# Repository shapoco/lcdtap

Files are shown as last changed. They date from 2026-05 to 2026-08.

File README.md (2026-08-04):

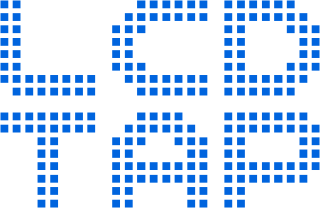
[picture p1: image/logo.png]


A library and its example design that receives LCD controller commands (via SPI or I2C)
and outputs the framebuffer as a DVI-D signal.

## Overview

See [introduction page](https://shapoco.github.io/lcdtap/).

## Implementations

### [LcdTap-Pico2 Universal](example/pico2_universal/)

Supports multiple LCD controllers (ST7789, ILI9341, SSD1306, SSD1331, ST7032)
and interfaces, selectable at runtime via an OSD menu.

### [LcdTap-Pico2W Remote](example/pico2w_remote/)

Raspberry Pi Pico 2 W version with no video output: the captured screen is
read over WiFi through an HTTP JSON API and a built-in web UI
(`http://lcdtap.local/`). WiFi setup via the
[Remote Setup page](https://shapoco.github.io/lcdtap/remote/) (WebSerial).

## License

MIT License — see [LICENSE](LICENSE).

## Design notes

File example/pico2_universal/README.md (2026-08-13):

# LcdTap-Pico2 Universal

A universal LCD-to-DVI converter example for Raspberry Pi Pico 2. With an OSD (On-Screen Display) menu for runtime configuration.

## Features

- Supports four input interfaces selectable via OSD: I2C, 4-Line SPI, 3-Line SPI, 8-bit Parallel
- Runtime configuration via OSD menu: interface, controller type, pixel format, LCD size, inversion, R/B swap, rotation, scale mode
- Settings (including selected interface) saved to flash on Apply and restored at next boot
- DVI output: 640×480@60Hz or 1280×720@30Hz selectable via GPIO21 at boot
- Composite video output (NTSC/PAL) on otherwise-unused GPIOs, selectable from the OSD: a 1-pin PWM DAC or a 7-bit R-2R ladder
- DisplayLink output: drives a USB graphics adapter (DisplayLink DL-1x0/1x5) at 1280×720 or 1920×1080@60Hz via a PIO USB Full-Speed host on GPIO10/11 (best-effort update rate)
- USB CDC serial interface for remote configuration and framebuffer readout from a PC or smartphone

> [!WARNING]
> Parallel Mode has not been tested yet. Please let me know if it works!

## Schematics

- Keep the input bus as short as possible and ensure all cables are the same length.
- See also: [Recommended Header Pinout](https://shapoco.github.io/lcdtap/#header_pinout)

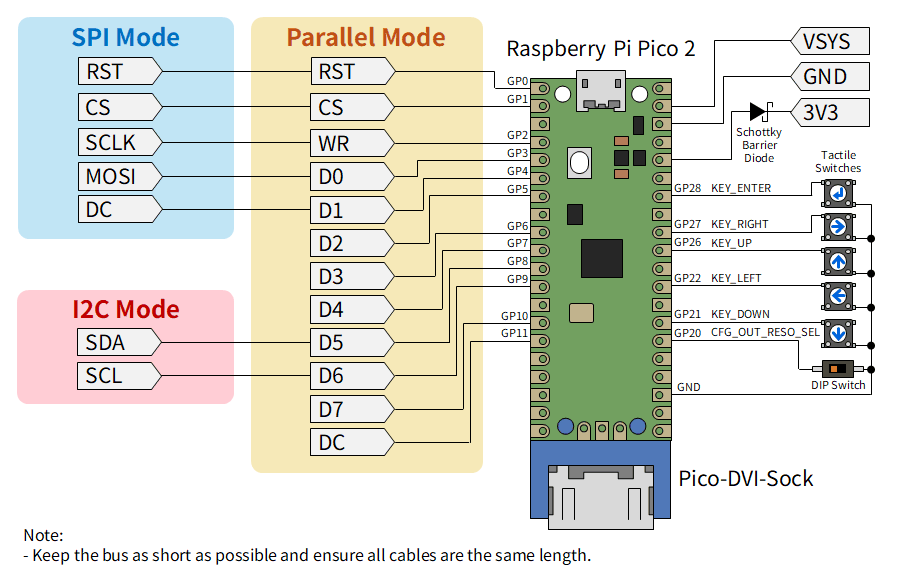
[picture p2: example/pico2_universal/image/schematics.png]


## GPIO Assignments

### Common (all modes)

| GPIO  | Direction | Name | Active-low | Internal Pull-up | Description |
|:--:|:--:|:--|:--:|:--:|:--|
| 0 | IN | RST | v | v | LCD Hardware reset (SPI mode) |
| 5–11  | OUT | CVBS_D[0..6] | | | Composite R-2R ladder (SPI modes only, when selected) |
| 10 | OUT | CVBS_PWM | | | Composite PWM output (SPI/I2C, when selected) |
| 10/11 | I/O | USB_DP / USB_DM | | | DisplayLink USB host D+/D- (SPI/I2C, when selected) |
| 12–19 | OUT | (DVI signals) | | | RP2350 HSTX |
| 20 | IN | CFG_OUT_RESO_SEL | v | v | High=640×480@60Hz,<br>Low=1280×720@30Hz |
| 21 | IN | KEY_DOWN | v | v | Low=pressed |
| 22 | IN | KEY_LEFT | v | v | Low=pressed |
| 26 | IN | KEY_UP | v | v | Low=pressed |
| 27 | IN | KEY_RIGHT | v | v | Low=pressed |
| 28 | IN | KEY_ENTER | v | v | Low=pressed |

### I2C Mode

| GPIO  | Direction | Name | Active-low | Internal Pull-up | Description |
|:--:|:--:|:--|:--:|:--:|:--|
| 8 | IN | SDA | | v | I2C data |
| 9 | IN | SCL | | v | I2C clock |

### 4-Line/3-Line SPI Mode

| GPIO  | Direction | Name | Active-low | Internal Pull-up | Description |
|:--:|:--:|:--|:--:|:--:|:--|
| 1 | IN | CS | v | v | LCD Chip select |
| 2 | IN | SCLK | | | SPI clock from master |
| 3 | IN | MOSI | | | SPI data from master |
| 4 | IN | DC | | | D/C# signal from master (4-line mode only) |

### Parallel Mode

| GPIO  | Direction | Name | Active-low | Internal Pull-up | Description |
|:--:|:--:|:--|:--:|:--:|:--|
| 1 | IN | CS | v | v | LCD Chip select|
| 2 | IN | WR | | | Write strobe |
| 3–10 | IN | D[0..7] | | | parallel data |
| 11 | IN | DC | | | D/C# signal |

For text displays, connect the R/W signal to CS and the E signal to WR.

For KS0108-compatible displays (such as SG12864), connect CS1 to RST,
CS2 to CS, and AND the inverted R/W signal with the E signal to connect to WR.
If R/W is fixed to Low, you can connect the E signal directly to the WR terminal.

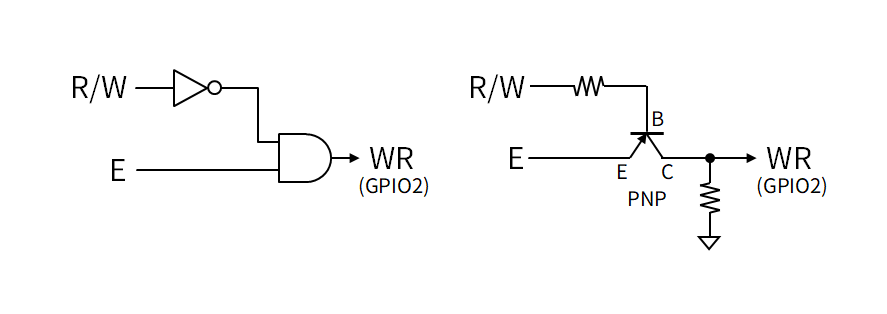
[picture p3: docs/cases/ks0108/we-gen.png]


## Composite Video Output (NTSC/PAL)

The HDMI connector occupies GPIO12–19, so composite video uses the GPIOs that
the input bus leaves free. Two independent OSD items control it (or
`outputInterface` / `compositeDac` over USB CDC):

- **`Output`** — `DVI-D`, `NTSC` or `PAL`
- **`Composite DAC`** — `PWM` or `R-2R`

There are therefore two quality tiers, and you only build the one you want:

| DAC | GPIO | Parts | Picture | Buses |
|:--|:--|:--|:--|:--|
| **PWM** | 10 | 1 resistor + 1 capacitor | ~12 luma steps, ~70% amplitude | SPI, I2C |
| **R-2R** | 5–11 | 14 resistors, no buffer | 7-bit luma, full amplitude | SPI only |

The R-2R ladder spans GPIO5–11, which covers the I2C pins (GPIO8/9), so it is
selectable only on SPI; the OSD greys it out otherwise. Composite output is
unavailable on the parallel bus entirely — GPIO3–10 are data lines there, which
covers the PWM pin too.

**The device resets** when `Output` changes (each mode needs a different system
clock), and when the bus or the DAC changes while a composite mode is running.

PAL colour is not implemented yet; PAL currently outputs monochrome on both
DACs.

> [!NOTE]
> Both DACs share GPIO10, so the two circuits are alternative populations, not
> simultaneous ones. Build whichever tier you want.

### PWM DAC — simple tier

One GPIO, one resistor, one capacitor. No buffer.

```
GPIO10 --- R ---+--- RCA centre
                |
                C
                |
               GND
```

The PWM period equals the sample period, so the duty resolution *is* the
sample period in system clocks: 22 steps on NTSC, 17 on PAL. White sits at
duty 17/22 rather than 100%, because chroma overshoots white by up to
+133 IRE and has to fit above it.

That, plus the 12 mA per-pin limit, is why the amplitude falls short of the
1 V standard — a single 3.3 V GPIO simply cannot reach it:

| R | White level | Sync amplitude | Peak current |
|:--|:--|:--|:--|
| 120 Ω | 0.78 V (78%) | 0.23 V (80%) | 13.5 mA |
| **150 Ω** | **0.70 V (70%)** | **0.21 V (72%)** | **12.0 mA** |
| 180 Ω | 0.63 V (63%) | 0.18 V (64%) | 10.8 mA |

Start at **R = 150 Ω** and drop to 120 Ω if a receiver refuses to lock.
Most TVs slice sync on the AC-coupled signal and tolerate this; capture
devices are less forgiving. C = 100–470 pF (corner ≈ 5–6 MHz).

The PWM carrier sits at 14.3 MHz with chroma at 3.58 MHz — only two octaves
apart — so a single-pole RC leaves visible carrier ripple. That is the
accepted cost of this tier.

### R-2R ladder — quality tier

The ladder drives the 75 Ω line **directly, with no buffer**. To deliver the
~1 V composite range into 75 Ω, its output impedance has to be low, so the
resistors are ~10× smaller than a textbook ladder: **R = 100 Ω series, 2R =
200 Ω rungs, 200 Ω termination.**

The firmware drives GPIO5 as the **LSB** and GPIO11 as the **MSB** (the PIO
maps sample bit 0 to the lowest GPIO). In an R-2R ladder the bit nearest the
output node has the greatest weight, so the **output is tapped at the GPIO11
(MSB) end** and the termination sits at the GPIO5 (LSB) end. Sync tip is 0 V at
the ladder, so it connects straight to the RCA centre — no coupling capacitor.

```
GPIO11 -- 200R --+---------------- RCA centre       (MSB, weight 64)
        (MSB)    |            |
               100R        (470pF)   optional reconstruction
                |            |        cap to GND (~6 MHz)
GPIO10 -- 200R --+          GND
                 :   (GPIO9, 8, 7, 6 identical)
               100R
                |
GPIO5  -- 200R --+                                  (LSB, weight 1)
        (LSB)    |
               200R    (2R termination)
                |
               GND
```

Wiring it the other way round — output at GPIO5, termination at GPIO11 —
reverses the bit weights and scrambles the picture, so double-check the
orientation.

2R = 200 Ω keeps the exact 2:1 R-2R ratio against the 100 Ω series resistor,
and in practice gives the most stable picture. The termination is another
200 Ω, so every rung and the termination share the same value.

Peak GPIO current is ~13 mA — just over the nominal 12 mA, which is fine here.
The drive strength stays at 12 mA (set in firmware).

> [!NOTE]
> These are a bench starting point. With a scope on a **50 % grey** field,
> confirm the mid-scale step is clean and monotonic.
>
> With nominal values the levels come out a few percent high (full scale
> ~1.4 V, white ~1.1 V, blanking ~0.3 V; sync tip 0 V). Trim this by scaling
> all three resistor families up together, or just leave it — the receiver
> works on relative levels. **Do not** retune it with `lvlWhite` / `lvlBlank`
> in `composite_timing.cpp`: those are shared with the PWM DAC. Use 1 %
> resistors, and keep 2R = 200 and the termination = 200 as a matched set.

## DisplayLink Output (USB)

Select `DisplayLink` as the `Output` (or `outputInterface = 3` over USB CDC) to
drive a USB graphics display adapter instead of the HDMI connector. The
adapter is driven by a PIO-based USB **Full-Speed** host
([Pico_USB_Disp](https://github.com/htlabnet/Pico_USB_Disp)) on GPIO10 (D+)
and GPIO11 (D−), so only the **DisplayLink DL-1x0 / DL-1x5** generation
works — newer chips (DL-3xxx and later) require High-Speed and encrypted
protocols. 1920×1080 needs a DL-165 or DL-195; smaller chips automatically
fall back to 1280×720.

- **Resolution** follows the CFG_OUT_RESO_SEL pin: open = 1280×720@60Hz,
  low = 1920×1080@60Hz (the DVI 480p/720p slots map to 720p/1080p).
- The adapter scans out a stable 60 Hz signal from its own framebuffer; the
  Pico streams **best-effort partial updates** over the ~1 MB/s bulk link.
  Only lines whose pixel values actually changed are re-sent, so mostly
  static screens update quickly; a full-screen change takes on the order of
  0.3–1 s (tearing can occur — there is no vsync over USB).
- Unavailable on the parallel bus (GPIO10/11 are D[7] and D/C# there), and
  mutually exclusive with the composite DACs, which share GPIO10.

Hardware: wire a USB-A receptacle with **5 V bus power (500 mA class)** to
the adapter, D+/D− to GPIO10/11. The 3.3 V GPIO levels match USB FS
signalling directly; series damping resistors up to ~47 Ω are tolerable at
Full-Speed (22–27 Ω preferred).

## Uploading Firmware

1. Download zip file from [releases](https://github.com/shapoco/lcdtap/releases).
2. Extract `lcdtap_pico2_universal.uf2` from the zip file.
3. Connect the Pico 2 to your computer while holding the BOOTSEL button to enter bootloader mode.
4. Copy the UF2 file to the mounted drive.

## OSD Menu

Press the Enter key to open the configuration menu.

| Key | Action |
|-----|---|
| Up / Down | Navigate menu items |
| Left / Right | Adjust selected value |
| Enter on Apply | Apply changes and save to flash |
| Enter on Cancel | Discard changes and close |
| Enter on Command Dump | Open the command dump viewer |

### Command Dump Viewer

Selecting **Command Dump** opens a hex viewer that shows the raw LCD command/data stream captured since power-on (or since the last trigger).

| Key | Action |
|-----|---|
| Enter | Clear buffer and start a new capture |
| Right | Stop capture (mark complete) |
| Left | Return to the configuration menu |
| Up / Down | Scroll |

Each row displays 16 entries. Colors indicate the type of each entry:

| Color | Meaning |
|---|---|
| Black on cyan | Command byte |
| White on black / dark-gray (alternating) | Data byte |
| Black on yellow (`HR`) | Hardware reset event |
| `..` in dark gray | Empty (not yet captured) |

## USB Serial Interface

LcdTap-Pico2 Universal accepts JSON commands over the USB CDC serial interface.
This allows remote configuration and framebuffer readout from a PC.

Available here: https://shapoco.github.io/lcdtap/monitor

## Building Firmware from Source

```bash
export PICO_SDK_PATH=/path/to/pico-sdk
./build.sh
```

The UF2 file is generated at `build/lcdtap_pico2_universal.uf2`.

### CMake Options

| Option | Default | Description |
|---|---|---|
| `LCDTAP_LCD_SIZE_W` | 240 | Initial LCD framebuffer width (px) |
| `LCDTAP_LCD_SIZE_H` | 320 | Initial LCD framebuffer height (px) |

Example:

```bash
cmake .. -DCMAKE_BUILD_TYPE=Release -DPICO_BOARD=pico2 \
         -DLCDTAP_LCD_SIZE_W=320 -DLCDTAP_LCD_SIZE_H=240
```

## External Deserializer for High-Speed SPI

The SPI interface of LcdTap-Pico2 Universal can support clock frequencies up to approximately 50MHz. For frequencies exceeding this, you can add an external deserializer outside the Pico2 to support higher speeds. In this case, select Parallel as the Interface in the OSD menu.

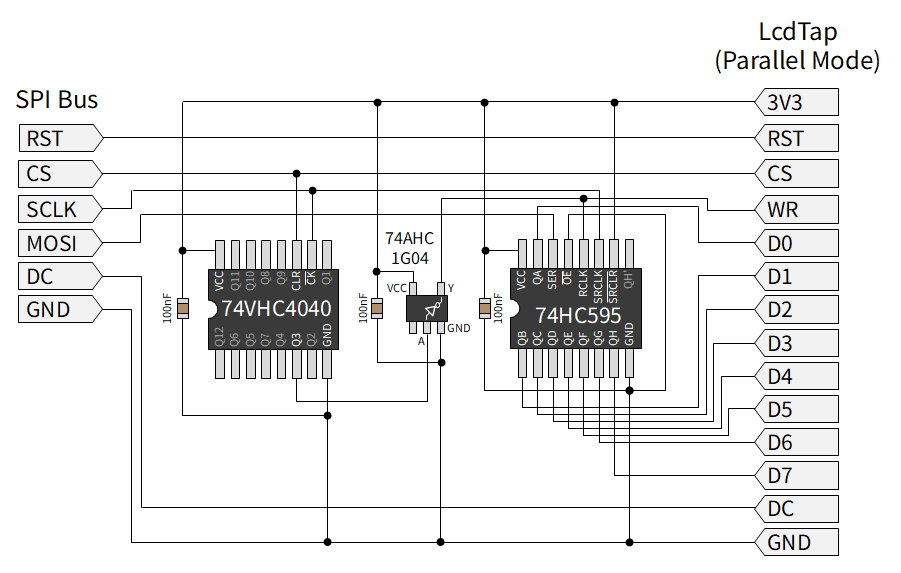
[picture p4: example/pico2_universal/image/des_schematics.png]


## Troubleshooting

### Failed to boot normally

Try powering on or resetting while pressing the Left key. This will boot while ignoring the settings saved in flash.

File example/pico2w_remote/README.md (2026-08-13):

# LcdTap pico2w_remote

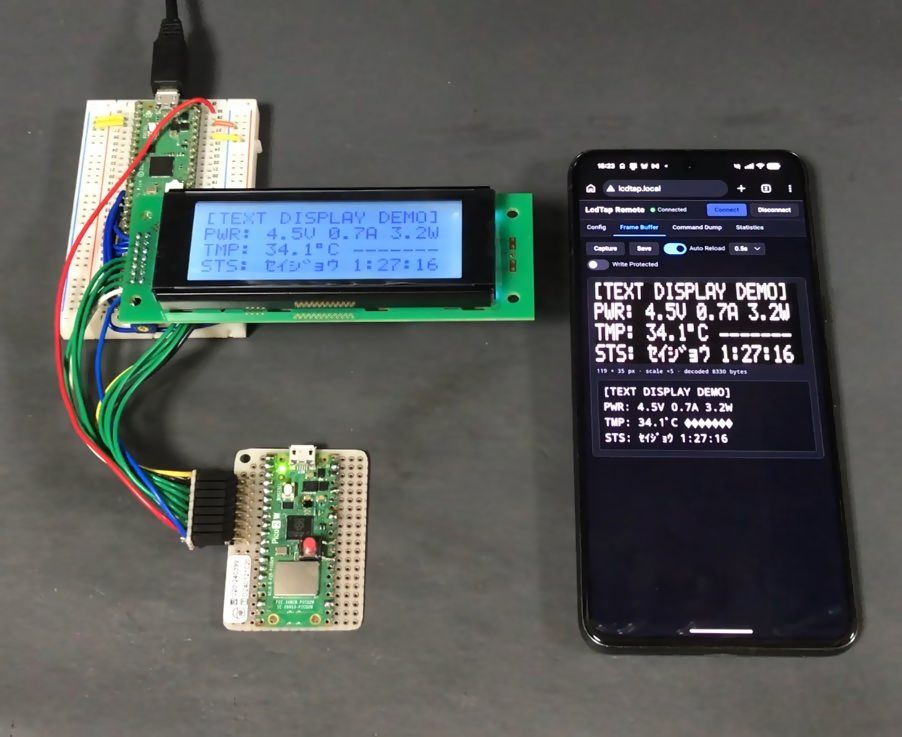
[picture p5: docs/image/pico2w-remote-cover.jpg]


LcdTap implementation for Raspberry Pi Pico 2 W. Using the same input interface as
pico2_universal (I2C / 4-wire SPI / 3-wire SPI / 8-bit parallel with identical pin layout),
it captures LCD controller traffic and reads the screen **without video output** via WiFi
through HTTP JSON API and built-in Web UI on the device.

## Features

- HTTP Server (port 80)
  - `GET /` — Web page with the same UI as LcdTap Monitor (firmware built-in)
  - `POST /api` — Same JSON command set as pico2_universal's UART I/F
- USB CDC Serial — Same JSON command set + WiFi setup
  (`getnetconfig` / `setnetconfig` / `netstatus`)
- mDNS — `http://<hostname>.local/` (default `lcdtap.local`)
- Settings are stored in Flash

## Setup

1. Download the latest zip file from [releases](https://github.com/shapoco/lcdtap/releases), and extract `lcdtap_pico2w_remote.uf2`.
2. Connect Raspberry Pi Pico 2 W to your PC while holding the BOOTSEL button, and copy the uf2 file to the mounted drive.
3. Open [LcdTap Remote Setup](https://shapoco.github.io/lcdtap/remote/) in your browser,
   connect via WebSerial, and write SSID / passphrase, etc.
4. Pico2W reboots and attempts WiFi connection. When connection succeeds,
   LED stays on, and you can open Web UI at `http://lcdtap.local/` (or IP address).

## LED

| State | Pattern |
|---|---|
| WiFi Not Configured | 0.25 s on / 0.75 s off |
| Connecting | 0.25 s on / 0.25 s off |
| Connection Failed (Retry Waiting) | 0.5 s on / 0.5 s off |
| Connected | Always on + 50 ms off pulse on access |

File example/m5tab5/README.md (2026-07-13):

# LcdTap-Tab5

An implementation example that lets the Tab5 act as an SPI/I2C-connected LCD
display. It receives LCD controller commands on the rear port (M-Bus /
Grove) and renders them via M5GFX onto the built-in 1280x720 MIPI-DSI panel.

## Features

### I2C slave

Use the Grove connector on the side of Tab5 as an I2C slave and draw on the
Tab5 screen using SSD1306-compatible commands. The I2C slave address is 0x3C.

### SPI slave

Use the M-Bus connector on the back of Tab5 as an SPI slave and draw on the
Tab5 screen with 4-wire SPI (MOSI/D/C/CS).
All signals including RST must be connected.

The input interface has I2C selected by default.
To switch to SPI, select 4-Line SPI in the Interface menu of the OSD.

### OSD and keypad

When you tap the screen, a semi-transparent keypad appears on the screen.
Tap the return key icon to open the OSD menu where you can change various settings.
Settings are saved on the Tab5 device.

### Support for controllers other than SSD1306

Other controllers besides SSD1306 can be selected in the OSD, but
they may not work correctly due to performance and hardware constraints.

## Wiring

| Signal | GPIO | Location | Notes |
|---|---|---|---|
| SPI SCK | G17 | M-Bus ||
| SPI MOSI | G16 | M-Bus ||
| SPI D/C | G18 | M-Bus | |
| SPI CS | G45 | M-Bus | active-low, pulled up |
| RST | G19 | M-Bus | active-low, pulled up, shared by SPI/I2C |
| (reserved) | G52 | M-Bus | Dummy clock for priming. **Leave unconnected** |
| (reserved) | G51 | M-Bus | CS substitute for priming (driven High). **Leave unconnected** |
| I2C SDA | G53 | Grove | Slave address 0x3C |
| I2C SCL | G54 | Grove | External pull-up (2.2k-10kΩ) recommended |

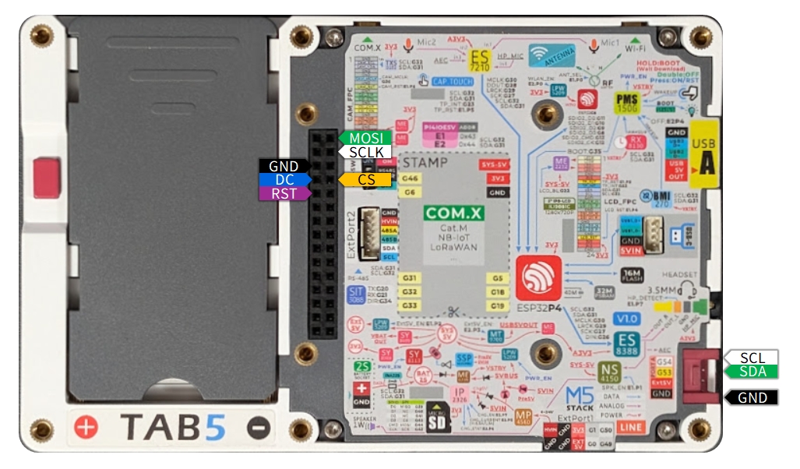
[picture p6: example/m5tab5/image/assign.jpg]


Notes on I2C wiring:

- Signal level is **3.3V only** (the ESP32-P4 is not 5V tolerant).
- If the original display is left connected in parallel on the bus, the
  address 0x3C collides, but reception (wired-AND) still works for both.
- Since clock stretching is not performed, this also works alongside
  bit-bang masters that don't check SCL (in exchange, reads return
  best-effort dummy values).

## Pre-built firmware

Pre-built firmware is available on the [M5Burner](https://docs.m5stack.com/en/uiflow/m5burner/intro). Search for "LcdTap".

## Build

Uses native ESP-IDF (idf.py). **ESP-IDF v5.5.x is required**
(the ESP-IDF build of M5GFX/M5Unified has only been verified up through
the v5.5.x series, and `i2c_slave.cpp` also requires
`ESP_IDF_VERSION >= 5.5`; v6.0 is not supported).

```sh
source <path-to-ESP-IDF>/export.sh
idf.py set-target esp32p4
idf.py build              # build
idf.py -p <PORT> flash    # flash
idf.py -p <PORT> monitor  # serial log (115200 bps)
```

Display, touch, IMU, and power bring-up use M5Unified/M5GFX as ESP-IDF
components (pulled in via `main/idf_component.yml`; `m5stack/m5gfx` is
pinned to an exact version because `async_blit.cpp` obtains the DSI
panel's raw framebuffer via an internal header).

The core library `lib/` is pulled in as an IDF component via
`EXTRA_COMPONENT_DIRS` in `CMakeLists.txt` (the `ESP_PLATFORM` branch in
`lib/CMakeLists.txt`). Its component name under IDF is derived from the
directory name, `lib` (see `REQUIRES` in `main/CMakeLists.txt`).

## Limitations / Notes

- Only **I2C** and **SPI (4-wire)** buses are supported. SPI 3-wire and
  8-bit parallel are not supported (selecting them in the OSD is
  ignored).
- Screen refresh is best-effort (LcdTap's framebuffer is transferred to
  the DSI panel in strips).
- The maximum SPI clock depends on the upper limit of PARLIO RX's
  external clock. Around 50 MHz is the target, but this needs to be confirmed
  by measurement on real hardware, including the effect of GPIO matrix
  delay.

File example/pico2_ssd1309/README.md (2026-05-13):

# Sample program for Raspberry Pi Pico2 — SSD1309

## Build instructions

```bash
cd example/pico2_ssd1309
mkdir build && cd build
cmake .. -DPICO_SDK_PATH=/path/to/pico-sdk
make -j4
```

## Input modes

This example supports two input modes, selectable via GPIO 20 at startup.

### I2C mode (default)

Connect the SSD1309 SDA and SCL lines directly to GPIO 0 and GPIO 1 with
4.7 kΩ pull-ups to 3.3 V. The Pico 2 acts as an I2C slave at address
`0x3C` (SA0 tied low). The SSD1309 I2C control byte (first byte after the
address phase) is decoded to determine whether subsequent bytes are commands
or GDDRAM data.

### SPI mode

SPI commands are received via a parallel conversion circuit — see
[example/pico2\_st7789/README.md](../pico2_st7789/README.md) for the full
description of the 74HC595 + 74HC4040 + 74AHC1G04 wiring and the BCLK/DCX signal path.
The pin assignment is identical to the ST7789 example.

## Pin assignment

| GPIO  | Direction | Function |
|---|---|---|
| 0 | IN | I2C SDA (I2C mode only) |
| 1 | IN | I2C SCL (I2C mode only) |
| 2 | IN | BCLK — byte clock = SCLK÷8 (SPI mode, 74AHC1G04 output, HIGH when byte complete) |
| 3 | IN | DCX — D/C# signal (SPI mode, direct from SPI master) |
| 4–11  | IN | D[0..7] — parallel data (SPI mode, 74HC595 Q1–Q8 outputs) |
| 12–19 | OUT | DVI TMDS output (pico\_sock\_cfg, driven by PicoDVI) |
| 20 | IN | CFG: input mode select |
| 21 | IN | CFG: DVI output resolution select |
| 22 | IN | RESX — hardware reset, active-low (SPI mode, pull-up on board) |
| 25 | OUT | Onboard LED |
| 26 | IN | CFG: output rotation bit 0 |
| 27 | IN | CFG: output rotation bit 1 |

## Configuration GPIOs

All configuration pins are read once at startup with internal pull-downs
(default = LOW). Pull HIGH to select the alternate option.

The output rotation is re-checked every DVI frame; changes take effect on the
next frame without restarting.

| GPIO  | Name | LOW (default) | HIGH (alternate) |
|---|---|---|---|
| 20 | INPUT\_MODE | I2C mode (default) | SPI mode |
| 21 | DVI\_RES | 640×480 @ 60 Hz | 1280×720 @ 30 Hz (reduced) |
| 26+27 | ROT | 00 = no rotation | 01/10/11 = see table below |

`ROT` is a 2-bit field: GPIO 27 is bit 1 (MSB) and GPIO 26 is bit 0 (LSB).

| ROT value | Effect |
|---|---|
| `00` | No rotation (default) |
| `01` | 90° clockwise — aspect ratio swapped for FIT |
| `10` | 180° / flip |
| `11` | 270° clockwise — aspect ratio swapped for FIT |

The scale mode is fixed to **FIT** (aspect-ratio-preserving letterbox /
pillarbox). The SSD1309 display is 128×64 pixels.

## DVI output (PicoDVI / libdvi)

DVI output is handled by [PicoDVI](https://github.com/Wren6991/PicoDVI)
(`libdvi`).

- **Core 1** runs `dvi_scanbuf_main_16bpp()` in an infinite loop, consuming
  RGB565 scanline buffers from the `q_colour_valid` queue and serialising TMDS
  data to the DVI connector via PIO0 and DMA.
- **Core 0** (main loop) calls `inst.fillScanline()` for each line and
  pushes the filled buffer to `q_colour_valid`.

The system clock is raised to match the TMDS bit-clock requirement (252 MHz for
640×480, 319.2 MHz for 1280×720 reduced), and the voltage regulator is set to
1.20 V to support these higher frequencies.

PicoDVI uses PIO0 and claims its DMA channels inside `dvi_init()`. In SPI mode,
the parallel slave PIO program runs on PIO1 (SM0), and its DMA channel is
claimed after `dvi_init()` to avoid conflicts.

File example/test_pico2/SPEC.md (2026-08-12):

# LcdTap Test Rig (test_pico2)

A Raspberry Pi Pico 2 W based semi-automated hardware test rig for the
LcdTap `pico2_universal` target. The rig plays the role of the LCD host:
it configures the target over its USB CDC JSON protocol, drives LCD
controller command streams into the target's SPI / I2C / 8-bit parallel
input as a bus master, reads the resulting framebuffer (or text buffer)
back over CDC, and verifies it against the transmitted pattern.

DVI-D / composite / DisplayLink outputs are checked visually and are out
of scope for automatic verification.

```
 PC ── USB ──┐                     ┌──────────────┐
             │  ┌──────────────┐   │ pico2_universal
   (console, │  │  Test rig    │───│  (target)
    Phase 2: ├──│  Pico 2 W    │   │
    UF2 pass │  │              │───│ LCD bus in
    through) │  └──────────────┘   └──────────────┘
             │     │        │
             │   OLED    keys x5
```

## Roles and phases

- **Phase 1 (this firmware)**: test execution. USB CDC host to the
  target (JSON protocol), bus master TX, streaming verification, OLED UI.
  Target BOOTSEL (MSC) presence is *detected* and shown as
  "Download Mode".
- **Phase 2 (implemented, on by default)**: USB MSC passthrough — while
  the target is in BOOTSEL, the rig exposes the RPI-RP2 drive to the PC
  ("TestRig Storage") and forwards UF2 writes, ported from the proven
  `mimicusb` project (`src/msc_bridge.cpp`): core 0 device callbacks
  defer with `TUD_MSC_RET_BUSY` while a single-slot cross-core handshake
  runs the block transfer on the core 1 host stack; target attach/detach
  is reported as SCSI media insert/remove (Unit Attention 0x28 / Not
  Ready 0x3A), so the drive letter stays put and only the medium comes
  and goes. Disable with `-DTESTRIG_MSC_PASSTHROUGH=0`. Note: MSC IO is
  only serviced while the UI is idle or between executor steps — do not
  flash the target while a test run is active.

## Hardware

### MCU / board

Raspberry Pi Pico 2 W (RP2350). The onboard LED (CYW43 WL_GPIO0) is a
heartbeat.

### Pin assignment

The bus port is wired straight to the target: **rig GPIO N → target
GPIO N−10**.

| Rig GPIO | Function | Target GPIO |
|---:|---|---:|
| 0 | UI OLED SDA (I2C0) | — |
| 1 | UI OLED SCL (I2C0) | — |
| 2 | Inc key (low active, pull-up, auto-repeat) | — |
| 3 | Dec key (low active, pull-up, auto-repeat) | — |
| 4 | Start key (low active, pull-up) | — |
| 5 | Select key (low active, pull-up) | — |
| 6 | Back key (low active, pull-up) | — |
| 8 | USB host D+ (Pico-PIO-USB) | target USB D+ |
| 9 | USB host D− | target USB D− |
| 10 | RST (active low) / 2CS: CS1 (high active) | 0 |
| 11 | CS (active low) / 2CS: CS2 (high active) | 1 |
| 12 | WR# / SCLK / 2CS: /EW strobe | 2 |
| 13 | D0 / SPI MOSI | 3 |
| 14 | D1 / SPI DC | 4 |
| 15–17 | D2–D4 | 5–7 |
| 18 | D5 / I2C SDA (i2c1) | 8 |
| 19 | D6 / I2C SCL (i2c1) | 9 |
| 20 | D7 | 10 |
| 21 | Parallel DC | 11 |

Only the pins of the active bus are driven; everything else on GPIO11–21
is kept high-impedance.

In PARALLEL_2CS (KS0108/KS0108) mode the same wires change roles: the
rig drives the raw high-active CS1/CS2 selects and the /EW strobe
directly (the target expects /EW = NAND(E, /R/W); the 8080 WR# waveform
of `par8_master.pio` is exactly that pulse), so no external gate logic
is needed. There is no reset input in this mode.

### External components (required)

- **GPIO8/9: ~15 kΩ pull-downs to GND.** RP2350 erratum E9 makes the
  internal pull-downs unreliable as USB host bus-reset terminations.
- SSD1306 128x64 I2C OLED on GPIO0/1 (address 0x3C), plus I2C pull-ups
  if the module has none.
- I2C pull-ups on the target bus lines (rig GPIO18/19) are recommended
  for the 1 MHz / 2 MHz settings; both sides also enable internal
  pull-ups.
- The rig must supply VBUS to the target's USB port.

## Clocking and on-chip resources

- `clk_sys` = **240 MHz** (multiple of 12 MHz for PIO-USB) with
  `VREG_VOLTAGE_1_15`.
- The SPI spec point of 62.5 MHz is intentionally replaced by
  **60 MHz** (240 MHz / 2 cycles-per-bit / divider 2): 62.5 MHz would
  require a 125/250 MHz clock, which PIO-USB cannot run from.
- PIO allocation: pio0 = PIO-USB TX, pio1 = PIO-USB RX, pio2 SM0 = bus
  master (SPI or parallel program, loaded on demand), CYW43 LED SPI
  claims a remaining SM (the init order in `main.cpp` steers it to
  pio2).
- Core 0: device USB (PC console), UI, executor. Core 1: TinyUSB host
  stack over PIO-USB (mount callbacks, CDC FIFO pumps). The cores
  exchange CDC bytes through lock-free SPSC rings.
- TX pattern buffer: one static 307.2 KB buffer (`TX_BUFFER_SIZE`,
  320×480 RGB565). Larger wire frames (320×480 RGB666 = 460.8 KB) are
  generated and sent in row chunks inside a single RAMWR.

## Bus master details

| Bus | Implementation | Rates |
|---|---|---|
| SPI mode 0 | PIO (pio2), 2 cycles/bit, MSB first; DC on GPIO14 switched between command/data phases after a TXSTALL drain | 10 / 20 / 40 / 60 MHz |
| 8-bit parallel | PIO, 3 cycles/byte: data setup with WR# low, target latches on the rising edge, 2-cycle hold (the target samples D+DC ~26 ns after the edge) | graphic: 1 / 2.5 / 5 / 10 MHz; character LCDs: 2 / 5 / 10 / 20 kHz (real HD44780-class modules such as the SC2004 need ~100 µs per byte) |
| I2C | hardware i2c1; control-byte framing per the target's parser (first byte per transaction: bit6 = D/C, Co=0 streams the rest) | 100 k / 400 k / 1 M / 2 MHz |

- For ST7032 targets the parallel strobe is inverted with
  `gpio_set_outover()`: the inverted 8080 WR# waveform is exactly the
  6800 E timing the target expects (`parWrInvert` on the target side).
- 2 MHz I2C is beyond the FM+ spec; it relies on the DW I2C timing
  registers accepting the divider. Validate on hardware; the vector can
  be treated as expected-fail if the silicon disagrees.
- CS is asserted for the whole test sequence and released at the end
  (SPI modes: the CS rising edge resets the target's capture state
  machine; parallel mode: the target discards strobes while CS is high,
  issue 0014).

## Test vectors

33 built-in vectors plus the **ALL** entry (runs every vector, continues
on failure). Defaults use the "Fast" clock (third choice of each
family/bus list: I2C 1 MHz, SPI 40 MHz, parallel 5 MHz — 10 kHz for
character LCDs, 500 kHz for the dual-CS parallel bus). See
`src/vectors.cpp` for the
full table: SSD1306 (I2C rot 0–3, SPI), SSD1331 (RGB332 rot 0–3,
RGB565, RGB666-RA), ST7789 (RGB444 rot 0–3, RGB565, RGB666-LA),
ILI9341, ILI9488 (RGB111 rot 0–3, RGB565, RGB666-LA, trim CUSTOM/AUTO,
parallel), ST7032 text presets (8x2/16x2/16x4/20x4 I2C, 20x4
parallel), and KS0108/KS0108 on the dual-CS parallel bus
(`KS0108_P8C2` per-chip page streams; `KS0108_CsMix` alternates the
cs mask per data byte with no commands in between, covering the bare
cs-change batch split in the target's `spiSlaveProcess2Cs`). KS0108
behaviours already proven by the host test
`example/pico2_common/test_host/ks0108_test.cpp` (start-line scroll,
column wrap, flip, per-chip display off, cs=3 data duplication) are not
re-tested on the rig.

Customization (per selected vector, volatile): bus interface,
resolution, pixel format, rotation, trim (Off / Custom / Auto with
x=11, y=15, w=width/2, h=height/2). Choice lists are constrained per
controller family. The bus clock is not per-vector: the global speed
class from the title screen picks index 0-3 of the same per-family/bus
frequency lists.

Formats that the controller command set cannot express are forced via
the target's `intfFmtOvr` setting: SSD1331 RGB666-RA (SETREMAP encodes
only RGB332/RGB565) and ILI9341-family RGB111 (COLMOD 0x01 unmapped).
Everything else is selected through real COLMOD / SETREMAP commands.

## Test procedure (per vector)

1. `getparams` for the vector's base preset; capture `swapRB`,
   `i2cAddr`, `textCols/Rows`.
2. Echo all preset values back via `setparams` with the vector's
   overrides (`busInterface`, `buffWidth/Height`, `trimMode/X/Y/W/H`,
   `outputRot`, `intfFmtOvr`, `flipMode=0`, `forcePwrOn=0`,
   `outputInterface=0`) plus **`"save": false`** so flash is not worn by
   automated runs. Keeping `outputInterface` at DVI-D avoids target
   reboots.
3. Wait 300 ms, `statsreset`.
4. Select the bus, pulse RST (10 ms low, 120 ms settle), send the
   controller init sequence (SWRESET/SLPOUT/COLMOD/MADCTL/DISPON etc.).
   PARALLEL_2CS vectors skip the RST pulse — the RST line is the CS1
   select in that mode; the target's `inputReset` on the `setparams`
   bus switch provides the state init instead.
5. Send 10 solid-color dummy frames (one row built once, resent per
   line), then immediately one PRNG compare frame. KS0108: dummy pages
   are written to both chips at once (cs=3); after the compare frame a
   few data bytes and a garbage command are sent with **no** chip
   selected — the discard is verified by the unchanged compare result
   and the zero `Unknown Commands` delta.
6. `getframebuffer {"writeProtected": true}` — the Base64/RLE stream is
   decoded and compared on the fly (below). Character LCD vectors send
   dummy text then per-row pattern text and compare via
   `gettextbuffer` (exact character codes).
7. `getstats`: the deltas of `RX Drop`, `RX HW Overflow` and
   `Unknown Commands` must be zero.

Pass = pixel/text compare AND clean stats. The result screen reports
the failed stage, mismatch count and first bad coordinate.

### Trim vectors

Auto trim on the target expands from the *addressed window*
(CASET/RASET), not from pixel content. AUTO vectors therefore address
only the trim rectangle (window, dummy and compare frames all confined
to it) and expect the readback region to equal it exactly. CUSTOM
vectors send the full frame; the target reports only the trim region.

## Verification engine

- **Pattern**: a counter-based hash PRNG (`hash32(seed ^ physIndex)`)
  gives O(1) random access to any pixel's canonical 8-bit RGB channels.
  Wire encoders emit the top N bits per channel for the vector's
  format; the expected RGB565 value derives from the same channels, so
  no expected-frame buffer exists anywhere.
- **Streaming compare**: the `getframebuffer` payload is fed character
  by character through Base64 → RGB565-RLE → pixel decode. The target
  emits the trim region in post-rotation order (`fbIndexTrimmed`); the
  verifier applies the same mapping back to physical coordinates,
  recomputes the expected hash and compares under a per-format
  significant-bit mask (e.g. RGB444 compares the top 4 bits of each
  channel), which removes any dependency on the target's low-bit
  expansion policy. `swapRB` swaps the compared fields and mask widths.
- Display inversion needs no special handling: the target XORs pixels
  on write and `getframebuffer` XORs them again with the same flag.
- Peak readback is ~410 KB of Base64 at Full-Speed USB (~1 s); nothing
  is buffered.

## UI

128x64 OLED (LovyanGFX, 6x8 font) and five tact switches (all
low-active with internal pull-ups, 1 ms sampling, level accepted after
3 identical samples). The Dec/Inc keys auto-repeat while held: first
repeat after 500 ms, then every 100 ms.

- **Title screen** (boot): run-wide options. `Intf` selects the target
  link (CDC over the PIO-USB port, or WiFi against pico2w_remote);
  `Freq` selects the global bus speed class Slow/Medium/Fast/Extra
  (index 0-3 into each family/bus frequency list; default Fast).
  Inc/Dec change the focused value, Select moves the focus, Start
  enters vector select (persisting changed options to flash and, for
  WiFi, starting the rig-side join), Back is ignored. A status line
  shows the rig's WiFi state / IP while WiFi is selected.
- **Vector select**: Inc/Dec scroll ALL / #1..#31; the title blinks.
  Start runs, Select customizes (not on ALL), Back returns to the
  title screen. The `Freq` line shows the clock the speed class
  resolves to for the vector's bus (informational).
- **Item select**: Inc/Dec pick Intf/Freq/Reso/Fmt/Rot/Trim (text
  vectors: Intf/Freq only); the item name blinks. Select edits, Back
  returns.
- **Value select**: Inc/Dec change the candidate; the value blinks.
  Select applies, Back cancels.
- **Running**: vector name + percent; Back cancels (between steps).
- **Result**: big OK/NG; on NG the failed list scrolls with Inc/Dec
  and the detail line shows stage / mismatch count / first bad pixel. Select
  jumps to customization of the selected failure, Back to vector
  select.
- **Download Mode**: while the target enumerates as MSC, the OLED
  blinks "Download Mode" and inputs are ignored; the previous screen is
  restored on exit.

The PC-facing CDC console logs pass/fail lines via `printf`
(`pico_stdio_usb` cannot coexist with `tinyusb_host`, so a minimal
custom stdio driver feeds the device CDC).

## WiFi mode (pico2w_remote target)

With `Intf: WiFi`, the run talks to a pico2w_remote target over HTTP
(`POST /api`, same JSON protocol) instead of CDC:

- The rig joins the WLAN with credentials stored in its flash (settings
  page below); DHCP only. `cyw43_arch_lwip_poll` + a minimal raw-TCP
  HTTP client (`src/link_http.cpp`, response parsing in
  `src/http_client.cpp`, host-tested by `test_host/http_test.cpp`).
- **The target's IP is discovered automatically**: at the start of every
  run the rig sends `netstatus` over the USB CDC link (the rig and
  target stay USB-connected in WiFi mode too) and uses the reported
  address. No target address is configured anywhere. If the target is
  not `CONNECTED`, every selected vector fails fast with stage
  `target-wifi`; if the rig's own WiFi is down, stage is `link`.
- One TCP connection per command: the target answers chunked with
  `Connection: close`, and the transport synthesizes the terminating
  newline on completion, so `JsonClient` runs unmodified. A `503`
  (target busy) is retried up to 3 times with a 200 ms backoff.
- The bus wiring, RST pulse and verification pipeline are identical to
  CDC mode. Note pico2w_remote's RGB111-at-40MHz limitation: run the
  Medium speed class for a clean ALL pass.

### Rig settings page (docs/test-pico2/)

A Web Serial page (same stack as docs/remote/) configures the rig's
SSID / passphrase / country over its PC-facing CDC and shows the join
state. It speaks `hello` (expects `"welcome testrig"` — distinguishes
the rig from a target), `getrigconfig`, `setrigconfig` and `netstatus`;
non-JSON console log lines are filtered (`jsonOnly` option of
serial_conn.js). Settings persist in the rig's last flash sector
(pico2_common flash_store; core 1 is parked in SRAM around the write)
and apply without a reboot.

## JSON protocol usage

See `example/pico2_common/UART_PROTOCOL.md`. The rig added the
`"save": false` option to `setparams` (apply without persisting) —
without it, every `setparams` costs a flash sector erase and a Core 1
pause on the target. The transport is abstracted (`Transport` in
`include/testrig/link.hpp`: `sendLine`/`recvChar`); a future
pico2w_remote HTTP transport (`POST /api`, same JSON) can replace the
CDC implementation without touching the executor.

## Build

```sh
git submodule update --init submodule/Pico-PIO-USB \
    submodule/ArduinoJson submodule/LovyanGFX
cd example/test_pico2
PICO_SDK_PATH=... ./build.sh      # PICO_BOARD=pico2_w
```

Host-side unit tests (no hardware; the closed loop runs the real lcdtap
library and the target's own RLE/Base64 encoders):

```sh
cd example/test_pico2/test_host
# build commands are in the header comments of:
#   testgen_test.cpp  — wire encoders vs reference decoders
#   verify_test.cpp   — closed loop: testgen -> LcdTap -> serialize -> verify
```

The closed-loop test found and pinned lib issue 0013 (RGB666-LA red LSB
leaking into green bit 10) before any hardware existed.

## Known limitations / future work

- Target parallel input is marked untested in pico2_universal — expect
  to shake out target-side issues; start at 1 MHz.
- Rotation vectors validate the config path, input decode and the
  rotated readback mapping; the DVI-side rendering itself remains a
  visual check.

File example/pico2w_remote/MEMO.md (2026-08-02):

# 実装メモ

- コア分担は pico2_universal と逆: **Core 1** が入力ドレイン
  (バス IRQ も Core 1 の NVIC に登録)、**Core 0** が cyw43/lwIP ポーリング
  + HTTP + USB CDC + LED。62.5 MHz SPI 入力が lwIP の処理バーストに
  影響されないための構成。
- Flash 書き込みとバス切替は Core 0 → Core 1 のメールボックスで依頼する
  (書き込み中 Core 1 は SRAM 上で待機)。
- clk_sys は実績のある 312 MHz (`sysClockInit312`)。CYW43 の PIO SPI は
  `CYW43_PIO_CLOCK_DIV_INT=4` で 39 MHz に抑えている。
- Web UI は `docs/monitor/` の共有ファイル (device.html / monitor.css /
  monitor.js / http_conn.js) をビルド時に gzip 圧縮して取り込む
  (`tools/embed_assets.py`)。GitHub Pages 版 Monitor と単一ソース。
- HTTP API は同時 1 リクエスト (2 本目は 503)。認証・暗号化は無いので
  信頼できる LAN 内での使用を前提とする。パスフレーズは Flash に平文で
  保存され、`getnetconfig` はパスフレーズを返さない。
- 既知の制限: CDC と HTTP の両方から `writeProtected:true` の
  getframebuffer を同時に実行すると、先に完了した側が書き込み保護を
  解除する (もう一方のキャプチャにティアリングが出る可能性)。

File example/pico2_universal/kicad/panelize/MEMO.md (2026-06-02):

# JLCPCB で位置の修正が必要だったパーツ

注文時のプレビュー上で修正して注文した

- RP2350: 向き
- HDMIコネクタ: 向きと位置
- USBコネクタ: 位置
- 1.1V レギュウｰレータのコイル: 向き
- 3.3V レギュレータ: 向き
- スライドスイッチ: 位置

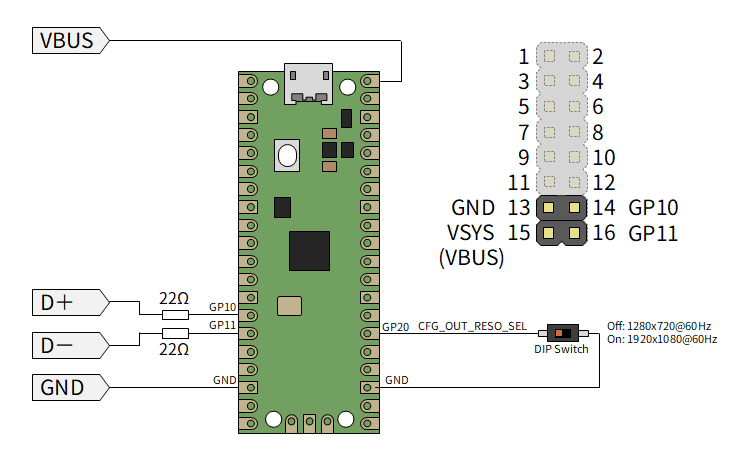
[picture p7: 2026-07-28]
docs/image/displaylink-out-schematics.png

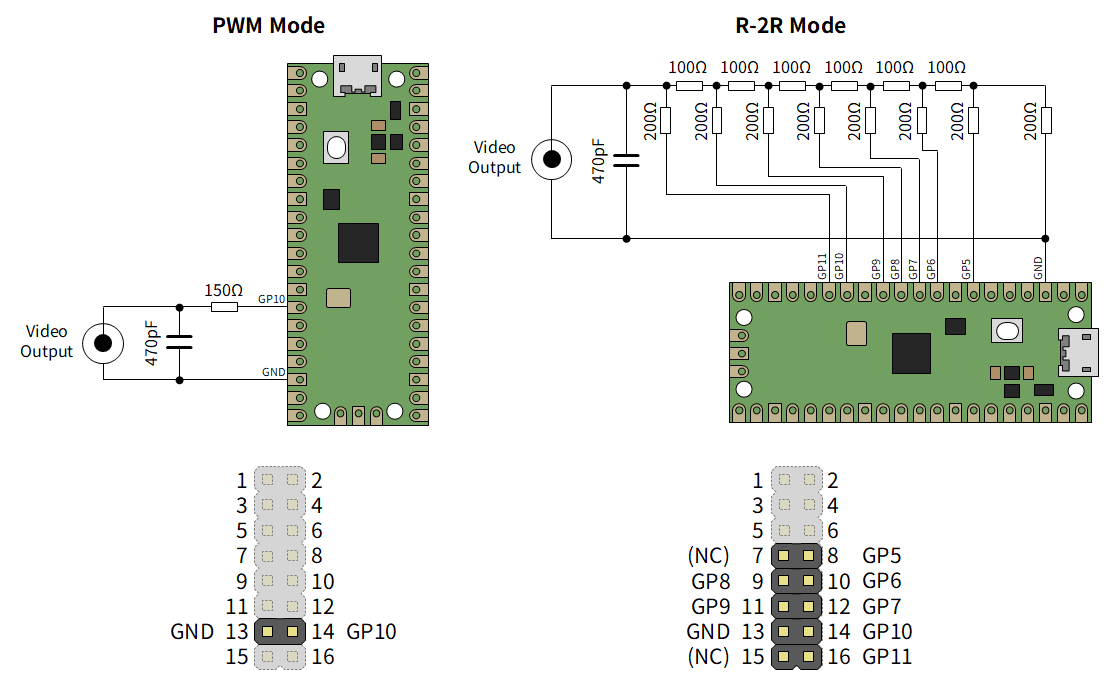
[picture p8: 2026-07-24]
docs/image/composite-out-schematics.png

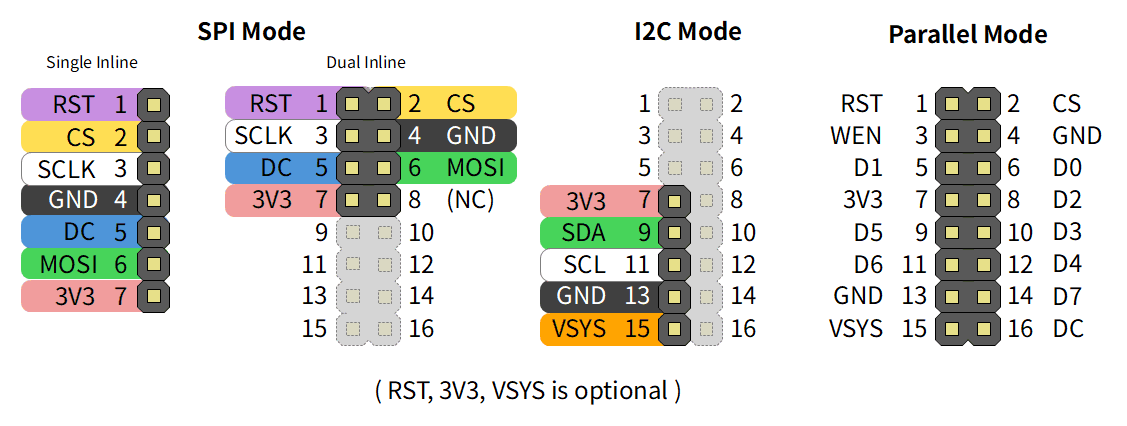
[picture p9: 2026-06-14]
docs/image/header-pinout.png

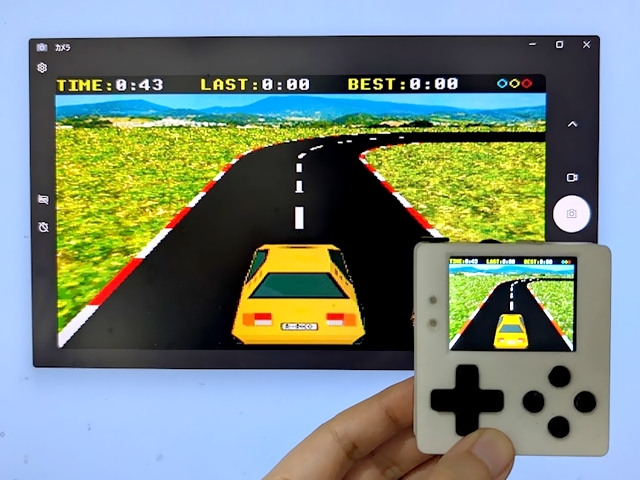
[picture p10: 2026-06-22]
docs/cases/picopad/thumb.jpg

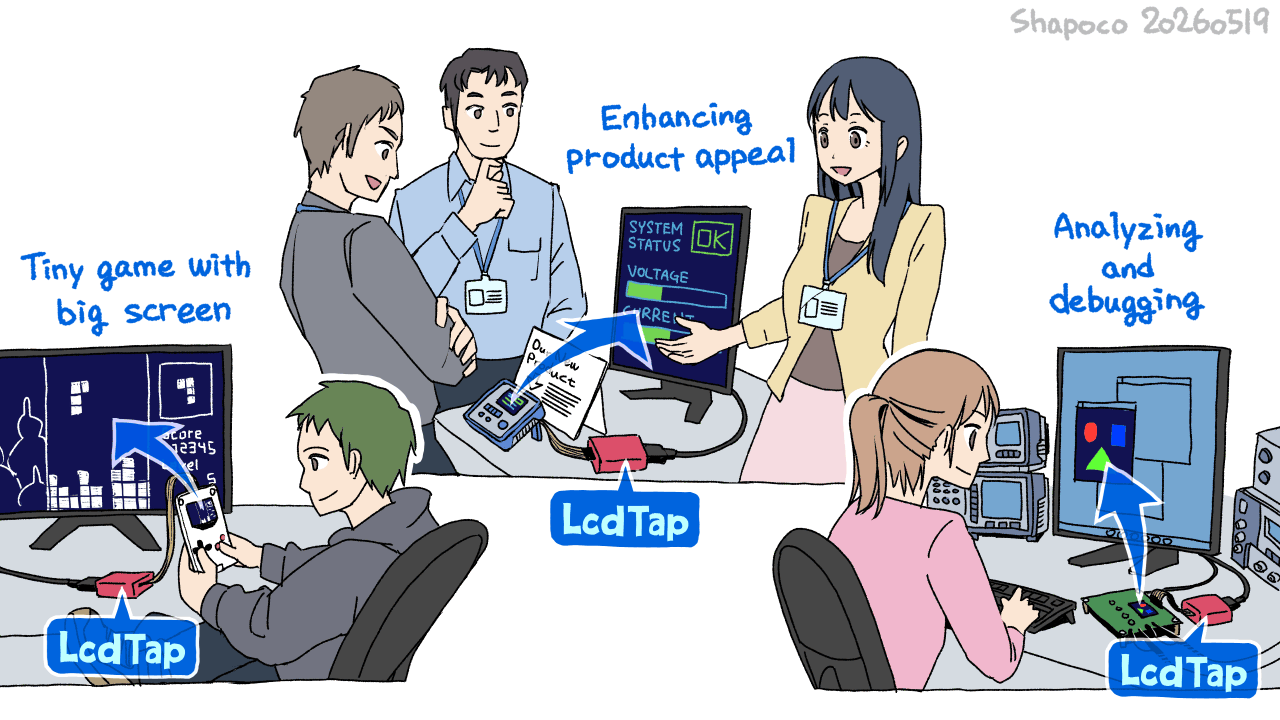
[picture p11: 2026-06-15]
docs/image/use-cases.png

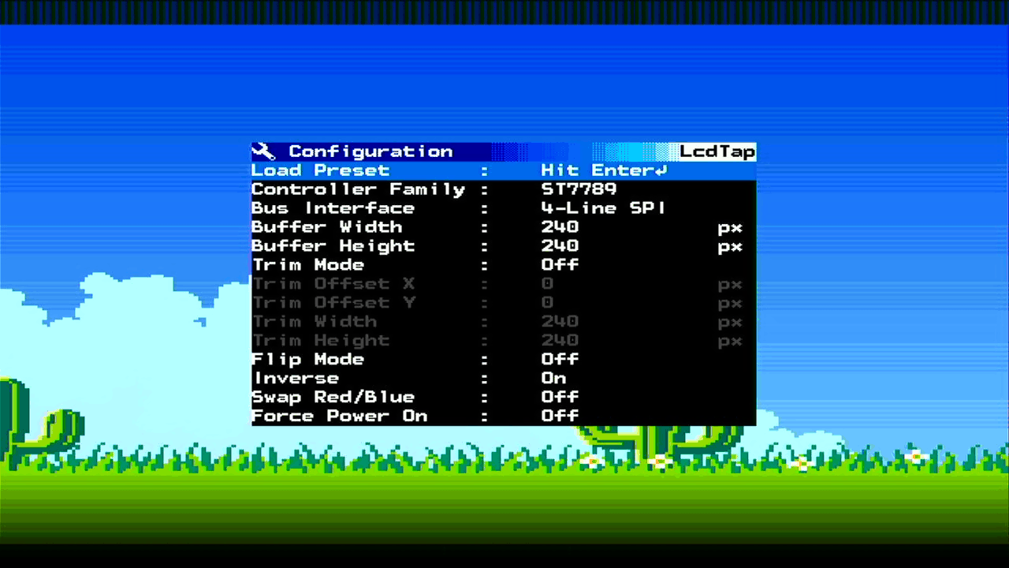
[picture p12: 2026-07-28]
docs/image/osd.png

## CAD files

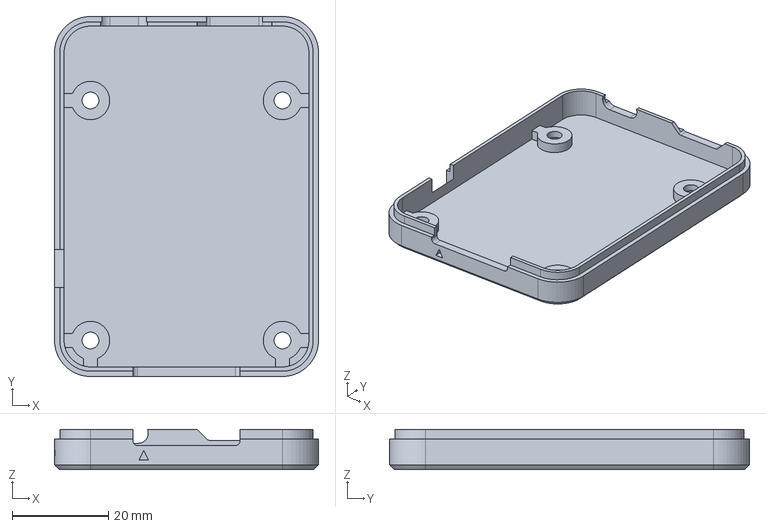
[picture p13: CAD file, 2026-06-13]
example/pico2_universal/enclosure/back_panel.step
55.0 x 75.0 x 8.40 mm

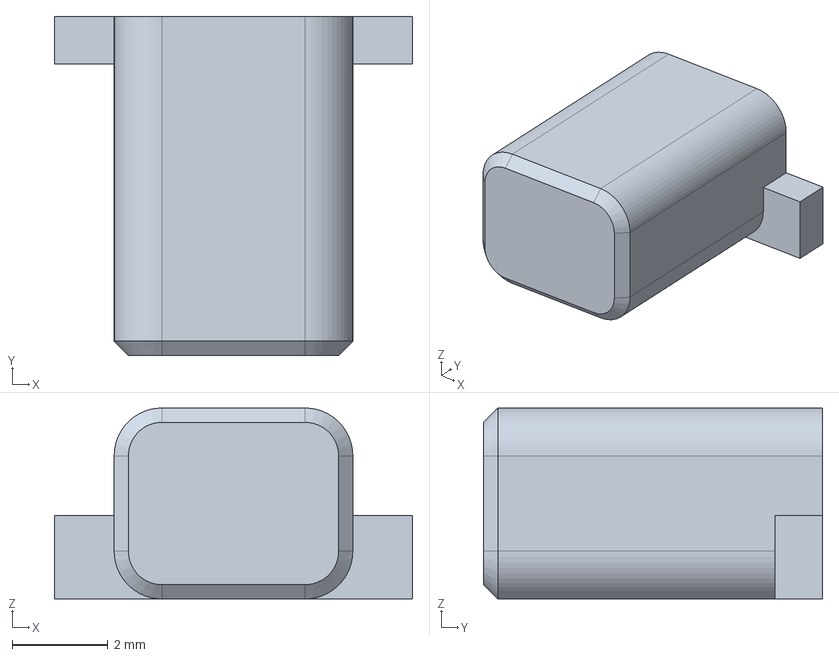
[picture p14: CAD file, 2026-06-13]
example/pico2_universal/enclosure/switch.step
7.50 x 7.10 x 4.00 mm

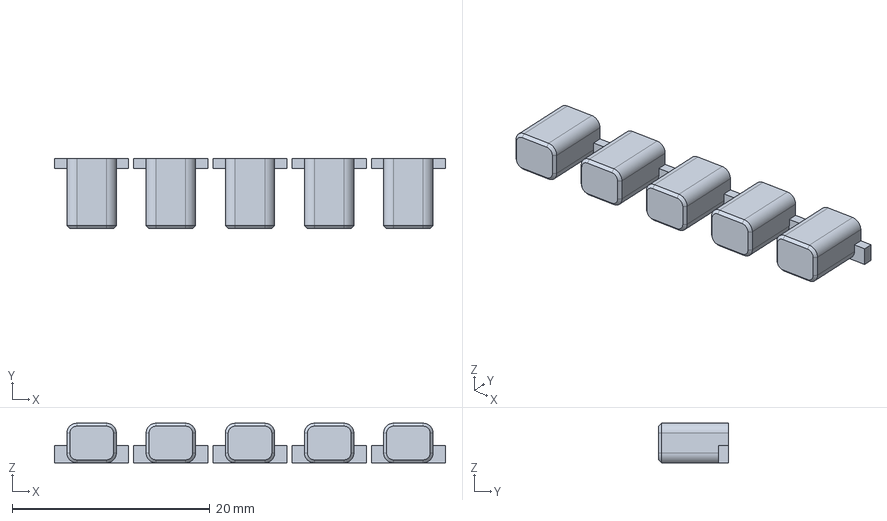
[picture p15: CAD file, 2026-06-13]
example/pico2_universal/enclosure/switch_set.step
39.5 x 7.10 x 4.00 mm

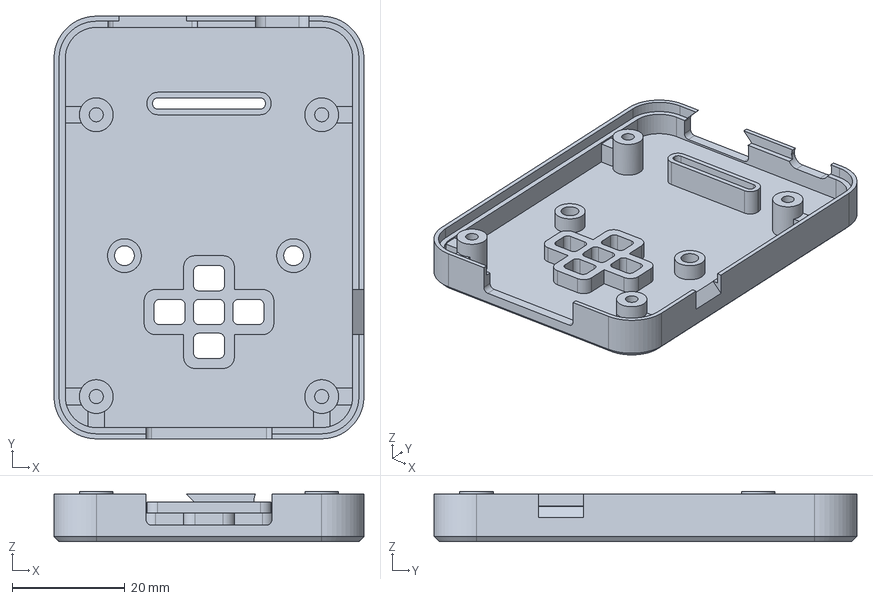
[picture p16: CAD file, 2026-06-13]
example/pico2_universal/enclosure/front_panel.step
55.0 x 75.0 x 8.90 mm

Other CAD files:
example/pico2_universal/enclosure/back_panel.stl
example/pico2_universal/enclosure/front_panel.stl
example/pico2_universal/enclosure/switch.stl
example/pico2_universal/enclosure/switch_set.stl

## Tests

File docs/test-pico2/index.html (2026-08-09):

# LcdTap Test Rig Setup

Disconnected

Connect Disconnect

Rig WiFi Settings (test_pico2)

Credentials for the rig to join the same WLAN as the pico2w_remote target. The target's IP address is discovered automatically over USB CDC, so there is nothing else to configure here.

SSID

Passphrase

Open network (no passphrase)

Country Code

ISO 3166-1 alpha-2; takes effect on next power cycle

Apply Reload

Rig Status

WiFi | –
SSID | –
IP Address | –
RSSI | –

WiFi joins when "Intf: WiFi" is selected on the rig's title screen.

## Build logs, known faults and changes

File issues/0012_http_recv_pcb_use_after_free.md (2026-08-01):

# 0012: pico2w_remote の HTTP 全応答が ERR_CONNECTION_RESET になる

- ステータス: 解決済み (3eacab0、実機確認済み: ページ表示・設定変更・キャプチャ取得 OK)
- 対象: example/pico2w_remote/src/http_server.cpp

## 症状

- WiFi 接続・ping 応答・USB CDC は正常。
- ブラウザで `http://lcdtap.local/` を開くと Pico 2 W の LED が 1 回
  点滅した後、Chrome が `ERR_CONNECTION_RESET` を表示しページが出ない。
- クラッシュはしていない (CDC 経由のキャプチャは継続して動作)。

## 原因

`onRecv()` (lwIP tcp_recv コールバック) の処理順の誤り:

```
if (c->state == RECV_REQ) {
  pbuf_copy_partial(...);
  tryDispatch(c);        // 小さい応答はここで送信完了し tcp_close() まで進む
}
tcp_recved(pcb, p->tot_len);   // ← 解放済み pcb への use-after-free
```

埋め込みアセットは gzip 済みで小さく、応答全体が TCP 送信バッファ
(8*MSS) に収まるため、`tryDispatch()` → `connPump()` → `tcp_close()` が
受信コールバック内で同期的に完走する。その直後に閉じた pcb へ
`tcp_recved()` を呼ぶため動作は未定義で、実機では RST 送出として現れた。
LED の 1 回点滅は accept 時の `ledActivityPulse()` で、症状と符合する。

## 修正

受信ウィンドウの解放 (`tcp_recved`) と `pbuf_free` を **dispatch より前**
に移動し、`tryDispatch()` 以降は pcb を触らない構造にした。他の
コールバック (onSent / onPoll) は connClose 後に pcb を参照しないことを
確認済み。

あわせて、POST /api ビジー時の 503 応答が 2 秒後の poll まで送信されない
問題も修正 (`startApiRequest()` 直後に `connPump()`)。

## 教訓

lwIP raw API のコールバック内で `tcp_close()` に到達しうる処理を呼ぶ
場合、その後に pcb を参照する処理 (`tcp_recved` 等) を残してはならない。
「小さい応答は recv コールバック内で完結する」ことを前提に順序を組む。

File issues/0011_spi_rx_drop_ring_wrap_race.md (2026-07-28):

# 0011: SPI RX Drop — リング一周境界での受信量再構成レース

## 症状

- SPI I/F で放置中に不定期な 1〜2 バイトの RX Drop が発生する。
    - Arduboy (75 kB/s): 数分に 1 回
    - M5Stack CoreS3 (5 MB/s): 数秒に 1 回
    - 発生頻度は RX Rate にほぼ比例
- Drop 発生の瞬間、RX Peak Backlog が**ちょうど 4096** (= リングワード数) になる。
  通常時の backlog は Arduboy で 12、CoreS3 で 260-270 程度。
- RX HW Overflow = 0、TX Underrun = 0。物理的な取りこぼしはない。
- I2C (TinyJoyPad, 15 kB/s) では発生しない。

## 原因

`spiSlaveProcess()` のオーバーラン検出は受信総量を

```
totalReceived = (wrapCount + pend) * ringWords + writeIdxNow
```

と再構成していた。wrapCount (DMA_IRQ_1 ハンドラが加算)、pend (INTS1 生フラグ)、
writeIdxNow (DMA `write_addr`) は更新タイミングが独立したハードウェア状態であり、
DMA がリングを一周した瞬間に「`write_addr` は base に巻き戻り済みだが、INTS1 の
セットがまだ CPU から見えない」数十 ns の窓がある。安定化 do-while は
wrapCount / pend の変化しか監視していないため、この窓でサンプリングすると
totalReceived が**ちょうど ringWords (4096) 過小**になる。

その後の連鎖:

1. backlog が負になり、「wrap IRQ 飢餓」向けのサイレント再同期が
   `totalConsumedWords = totalReceived` と消費カウンタを 4096 小さく破壊する。
2. 数 µs 後の次の呼び出しでは wrapCount/INTS1 が正しく見えるため
   backlog = 実滞留 + 4096 になる。
    - 実滞留 0: backlog == 4096 ちょうど → ドロップ判定 (`> ringWords`) は偽。
      **Peak Backlog に 4096 が記録される**だけ。
    - 実滞留 ≥ 1: 「追い越し」誤検出 → `readIdx = writeIdxNow` で
      実際に滞留していた 1〜2 バイトを読み飛ばす。**これが観測された Drop**。

つまり本物のリングバッファ追い越しは発生しておらず、誤検出の回復処理が
自らデータを捨てていた。レースはリング一周 (wrap) のたびに
「ポーリング頻度 × 競合窓幅」の確率で起こるため、発生頻度がレートに比例する。
I2C スレーブは IRQ ハンドラがソフトウェアで writeIdx を進める方式で
wrap 再構成を使っていないため影響しない。

## 修正

受信総量の主導出を write pointer の差分累積に変更した:

- 毎回 `totalReceivedWords += (writeIdxNow - lastWriteIdx) & (ringWords - 1)`。
  この値は**過大になり得ず**、呼び出し間にリングを丸一周以上された場合
  (= 検出したい本物のオーバーラン) だけ過小になる。
- wrap カウント方式の値 (`wrapBased`) は丸一周検出専用に残し、
  `wrapBased` が先行しているときだけ採用する
  (`(int32_t)(wrapBased - totalReceivedWords) > 0` → 上書き)。
  同一コア (main ループと DMA_IRQ_1 は共に Core 0) では wrapBased が
  過大側にずれる経路はないため、この片側採用は安全。
- backlog は構造的に非負になるため、消費カウンタを書き換える
  サイレント再同期を削除 (負値クランプのみ防御的に残置)。
- `spiSlaveInitDma()` で IRQ 有効化前に残留ペンディング INTS1 をクリア。

wrap IRQ が抑止されるケース (flash 書き込み中など) で複数 wrap が 1 回に
まとめられた場合、dropWords が下限値になる点は従来と同じ。

## 検証

- CoreS3 / Arduboy を接続して放置し、RX Drop = 0・Peak Backlog が通常値の
  ままであることを確認する。
- 回帰: SPI↔I2C 切替、CoreS3 ストリーミング中の設定保存 (flash 書き込み)。

## 結果

実機確認済み (2026-07-28)。修正後は RX Drop が発生しなくなった。解決。

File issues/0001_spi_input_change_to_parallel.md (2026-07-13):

# SPI 入力をパラレルにする

## 概要

SPI スレーブの受信のスループットが足りないため、SPI 入力と Raspberry Pi Pico2 の間にシフトレジスタと分周器を挿入し、SPI 入力をパラレルに変換する。

## 変更内容

SPI 入力の MOSI と SCLK を 8 ビットシフトレジスタ IC 74HC4094 に接続し、パラレル出力を Pico 2 に入力する。

SCLK はカウンタで分周した上で Pico 2 に入力する。カウンタには 74HC4040 を使用し、SCLK の立ち下がりでカウントアップする。カウンタの CLR 端子に CS を接続して CS=High でゼロクリアすることで、CS がアサートされていない間はクロックが Pico 2 に入力されないようにする。

CS=High のときはクロックが Pico 2 に入力されないので Pico 2 は CS を見る必要が無く、単に SCLK/8 の立ち下がりでパラレルデータと DCX をサンプリングすればよい。

```
CS      111100000000000000000000000000000000001111
SCLK    000000101010101010101010101010101010100000
DCX     xxxxx00000000000000001111111111111111xxxxx
MOSI    xxxxxAABBCCDDEEFFGGHHIIJJKKLLMMNNOOPPxxxxx

counter 000000011223344556677001122334455667700000
SCLK/8  000000000000011111111000000001111111100000
Q1      xxxxxxxxxxxxxxxxxxxxxHHHHHHHHHHHHHHHHPPPPP
Q2      xxxxxxxxxxxxxxxxxxxxxGGGGGGGGGGGGGGGGOOOOO
Q3      xxxxxxxxxxxxxxxxxxxxxFFFFFFFFFFFFFFFFNNNNN
Q4      xxxxxxxxxxxxxxxxxxxxxEEEEEEEEEEEEEEEEMMMMM
Q5      xxxxxxxxxxxxxxxxxxxxxDDDDDDDDDDDDDDDDLLLLL
Q6      xxxxxxxxxxxxxxxxxxxxxCCCCCCCCCCCCCCCCKKKKK
Q7      xxxxxxxxxxxxxxxxxxxxxBBBBBBBBBBBBBBBBJJJJJ
Q8      xxxxxxxxxxxxxxxxxxxxxAAAAAAAAAAAAAAAAIIIII
sampling                     ^               ^
```

SCLK は最大 62.5 MHz なので、SCLK/8 は最大 7.8125MHz となる。

## ピンアサイン変更

| GPIO | 旧 | 新 |
|---|----|----|
| 2 | SPI SCK | PAR BCLK（SCLK/8, 74HC4040 Q3） |
| 3 | SPI MOSI | PAR DCX（JMP_PIN） |
| 4 | SPI DCX | PAR D[0]（74HC4094 Q1, LSB） |
| 5 | SPI CS | PAR D[1]（74HC4094 Q2） |
| 6 | SPI RST | PAR D[2]（74HC4094 Q3） |
| 7 | DBG_FRAME | PAR D[3]（74HC4094 Q4） |
| 8 | — | PAR D[4]（74HC4094 Q5） |
| 9 | — | PAR D[5]（74HC4094 Q6） |
| 10 | CFG_SCALE_MODE0 | PAR D[6]（74HC4094 Q7） |
| 11 | CFG_SCALE_MODE1 | PAR D[7]（74HC4094 Q8, MSB） |
| 12-19 | DVI（変更なし） | DVI（変更なし） |
| 20 | CFG_LCD_SIZE（変更なし） | 変更なし |
| 21 | CFG_DVI_RES（変更なし） | 変更なし |
| 22 | — | PAR RST（旧 GPIO 6） |
| 25 | LED（変更なし） | 変更なし |
| 26 | — | CFG_SCALE_MODE0（旧 GPIO 10） |
| 27 | — | CFG_SCALE_MODE1（旧 GPIO 11） |
| 28 | — | DBG_FRAME（旧 GPIO 7） |

`in pins, 8` (LEFT shift, IN_BASE=GPIO 4) のビット対応：
- ISR[0] = GPIO 4 = 74HC4094 Q1 = D0（LSB、最後に入ったビット）
- ISR[7] = GPIO 11 = 74HC4094 Q8 = D7（MSB、最初に入ったビット）
- `in y,1` の後に `in pins,8` を実行 → bit[8]=DCX, bits[7:0]=バイト（旧フォーマットを維持）

## ファームウェア変更

### spi_slave.pio → par_slave.pio（全面書き換え）

旧: 62.5MHz SCLK を 1 ビットずつサンプリング（4 PIO サイクル/ビット）
新: SCLK/8 の立ち下がりを待ってパラレルサンプリング（余裕十分）

```asm
.define public PAR_BCLK_PIN  2

.program par_slave_with_dcx
    wait 0 gpio PAR_BCLK_PIN    ; スタートアップ同期

.wrap_target
    wait 1 gpio PAR_BCLK_PIN    ; SCLK/8 立ち上がり待ち（4クロック目）
    wait 0 gpio PAR_BCLK_PIN    ; SCLK/8 立ち下がり待ち（バイト確定）

    set  y, 0
    jmp  pin, dcx_high
    jmp  do_sample
dcx_high:
    set  y, 1
do_sample:
    in   y, 1        ; DCX → ISR bit[8]（8シフト後）
    in   pins, 8     ; D[7:0] をパラレルサンプリング
    push noblock
.wrap
```

ビットループが不要になりインストラクション数が大幅に削減された。

### config.h

- `PIN_SPI_*` → `PIN_PAR_*` に全面変更
- CS ピンの定数を削除
- RST → GPIO 22、CFG_SCALE_MODE0/1 → GPIO 26/27、DBG_FRAME → GPIO 28 に移動

### main.cpp

- `spi_slave_init()` → `par_slave_init()` に置き換え（データピン 8 本をループで初期化）
- CS 関連変数（`spi_cs_sync_idx`, `spi_cs_sync_pending`）と同期ロジックを削除
- CS の GPIO IRQ 登録を削除
- DMA・リングバッファ処理・dispatch ロジックは変更なし

### CMakeLists.txt

- `pico_generate_pio_header` の対象を `par_slave.pio` に変更

## 結果

映像出力に成功。

根本原因は断定できていないが、旧実装で DCX=Low（コマンドバイト）が正しく受信
できていなかった問題（`issues/0001` 参照）は本変更で解消した。
DCX が CS アサート後しばらく変化するようなタイミング（セットアップ違反）であっても、
SCLK/8 立ち下がりでのサンプリングであれば常に安定した DCX 値を取得できるため、
タイミング余裕の改善が DCX 誤読の解消に直結したと推測される。

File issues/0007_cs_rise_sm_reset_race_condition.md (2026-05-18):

# 0007: CS Rise SM Reset Race Condition

## 現象

CS の立ち上がりエッジで PIO ステートマシン (SM) を初期化する処理を実装していたが、CS
がすぐに再び立ち下がって次のコマンドが入力された場合に、CPU からの SM 初期化が間に
合わずコマンドが抜け落ちる現象があった。

## 原因

`gpioIrqHandler` 内で CS 立ち上がりを検出し、`resetPioSm()` を呼び出して SM を停止・
FIFO クリア・再起動していた。しかし、CPU ベースの割り込みハンドラ実行には一定のレイ
テンシが伴うため、CS が短時間で再アサートされると SM 初期化の完了前に次のビットが
入力され始め、先頭データが欠落した。

## 対処

CS 立ち上がりエッジによる SM 初期化機能を削除した。

削除した処理:
- `gpioIrqHandler` 内の `GPIO_IRQ_EDGE_RISE` ブロック (`resetPioSm()` 呼び出し)
- `switchInterface` / 初期化コードの `gpio_set_irq_enabled(PIN_SPI_CS, GPIO_IRQ_EDGE_RISE, ...)` 呼び出し

RST ピンのエッジ割り込みによる SM リセット (`resetPioSm()`) は引き続き動作する。

## 対象ファイル

- `example/pico2_universal/src/main.cpp`
- `example/pico2_st7789/src/main.cpp`
- `example/pico2_ssd1306/src/main.cpp`

## 補足

CS ごとの SM リセットが本来目的としていた「部分受信バイトの破棄」については、DMA
リングバッファ方式では実用上問題が顕在化していない。SPI 通信が正常に行われる限り CS
はバイト境界で立ち上がるため、SM のビット位相がずれたまま次のトランザクションに持
ち越されるリスクは低い。

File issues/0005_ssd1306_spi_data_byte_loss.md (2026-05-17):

# SSD1306 4-Line SPI でデータバイトが欠落し水平方向にズレが生じる

## 現象

`pico2_universal` で SSD1306 を 4-Line SPI + Horizontal Addressing Mode で使用すると、フレームバッファに書き込まれる画像が page ごとに数ピクセルずつ水平方向にズレていく。

- SPI クロック 8 MHz (平均 600 kHz 程度) での発生を確認。
- ST7789 + 4-Line SPI では同様の現象は起きない。
- SSD1306 + I2C モードでも起きない。

## 解析

`Ssd1306Controller::processRamwrData` のループ境界が基底クラス `ControllerBase::processRamwrData` と異なる規約になっていた。

基底クラスは `numBytes`（要素数）を受け取り `length = numBytes * stride` に変換してからバイトオフセットのループ上限に使うが、SSD1306 の override は変換を行わず `numBytes` をそのまま上限に使っていた。

```cpp
// 基底クラス (lib/src/lcdtap.cpp)
int32_t length = numBytes * stride;          // 要素数 → バイト数に変換
for (int32_t i = 0; i < length; i += stride) { ... }

// SSD1306 override の誤り (lib/src/ssd1306_controller.cpp)
for (uint32_t i = 0; i < length; i += stride) { ... }  // length = numBytes のまま
```

`stride = sizeof(uint32_t) = 4` のとき、ループが `numBytes / stride` 回しか回らず、バッチサイズが 2 以上になると最大 75% のバイトが処理されない。

`processSpiRingBuf()` は DVI スキャンライン同期で高頻度に呼ばれ、1 回あたりのバッチは平均 1〜2 ワード程度。バッチサイズ 2〜4 で 1〜3 バイトが欠落する。Horizontal Addressing Mode では page 間にアドレスリセットコマンドが来ないため、欠落が累積して page ごとに数ピクセルずつのズレとして現れる。

ST7789 では基底クラスの override を使うため正常。I2C では受信レートが低くバッチサイズがほぼ 1 になるためバグが顕在化しない。

## 対応

`Ssd1306Controller::processRamwrData` に基底クラスと同じ変換を追加した。

```cpp
// lib/src/ssd1306_controller.cpp
const uint32_t byteLen = numElems * stride;
for (uint32_t i = 0; i < byteLen; i += stride) { ... }
```

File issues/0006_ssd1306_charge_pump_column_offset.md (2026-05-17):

# SSD1306 初期化後の書き込み開始位置がずれる (CMD_CHARGE_PUMP 未処理)

## 現象

`pico2_universal` で SSD1306 を使用すると、フレームバッファの書き込み開始位置が column 0 にならず、画像の左上隅がフレームバッファの左上隅と一致しない。

- 一番上の page の中央あたり (column 64) から書き込みが始まる。
- 右下隅でラップアラウンドし、最後の約 1/2 page 分が左上隅から現れる。
- SSD1306 実機では正常に表示されているため、マスタ側の初期化コマンドは正しい。

## 解析

`CMD_CHARGE_PUMP (0x8D)` がコマンドヘッダにも `dispatchCommand` にも定義されておらず、`default: break;` に落ちるため `expectedParams = 0` のままになる。

続くパラメータバイト `0x14` (Charge Pump Enable) が新たなコマンドとして処理される。`0x14` は `CMD_SET_HIGHER_COL_BASE (0x10)–0x1F` の範囲に一致するため、`applyPageModeCol()` が呼ばれて意図せず `pageColHigh = 0x40, ramwrX = 64` に設定される。

```
0x8D → default (expectedParams=0 のまま)
0x14 → CMD_SET_HIGHER_COL: pageColHigh = (0x14 & 0x0F) << 4 = 0x40
         applyPageModeCol() → ramwrX = 0x40 | pageColLow = 64
```

その後の初期化シーケンスで `CMD_SET_COL_ADDR (0x21, 0x00, 0x7F)` が送られる場合は `ramwrX` が 0 にリセットされるが、送られない場合や `0x8D, 0x14` より前に送られる場合はオフセットが残ったままデータ送信が始まる。

## 対応

`CMD_CHARGE_PUMP = 0x8D` を `lib/include/lcdtap/devices/ssd1306.hpp` に追加し、`dispatchCommand` の switch 文に 1 パラメータコマンドとして登録した。

```cpp
// lib/include/lcdtap/devices/ssd1306.hpp
static constexpr uint8_t CMD_CHARGE_PUMP = 0x8Du;

// lib/src/ssd1306_controller.cpp
case CMD_CHARGE_PUMP: expectedParams = 1; break;
```

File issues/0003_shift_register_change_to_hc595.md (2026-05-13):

# シフトレジスタ IC を 74HC595 に変更

コミット: 2f4935bd801c69ca9c66d9e0da3b0855d7c7fe58

## 概要

SPI クロックの高速化（最大 62.5 MHz）に対応するため、シリアル→パラレル変換に使用する
シフトレジスタ IC を 74HC4094 から 74HC595 に変更した。

## 変更理由

74HC4094 は CP（クロック）入力の立ち上がりでシリアルデータをシフトし、ST（ストローブ）
入力の立ち上がりで Q 出力を更新する構成だった。高速クロックでの動作において出力の
セットアップ・ホールドタイミングに余裕がなく、動作の信頼性に問題があった。

74HC595 は SRCLK（シフトレジスタクロック）の立ち上がりで取り込み、RCLK（ラッチクロック）
の立ち上がりで Q 出力を更新するため、74HC4040 との組み合わせで安定した動作が得られる。

## 回路変更

### シフトレジスタ

| 旧 | 新 |
|----|----|
| 74HC4094 | 74HC595 |
| CP ← SPI SCLK | SRCLK ← SPI SCLK |
| DS ← SPI MOSI | SER ← SPI MOSI |
| ST ← （未接続 or 固定 HIGH） | RCLK ← 74AHC1G04 出力（BCLK） |

### BCLK ラインへのインバータ追加

74HC4040 Q3 出力（SCLK/8）は 74AHC1G04 シングルインバータを通して BCLK を生成するよう変更した。

```
SPI SCLK ──→ 74HC4040 CP
SPI CS   ──→ 74HC4040 CLR（active-high）
74HC4040 Q3 ──→ 74AHC1G04 IN ──→ BCLK ──┬──→ Pico 2 GPIO 2
                                         └──→ 74HC595 RCLK
```

変更前は 74HC4040 Q3 が直接 Pico 2 に入力されていた。
変更後は 74AHC1G04 で反転した後の信号が BCLK として Pico 2 および 74HC595 RCLK に入力される。

### BCLK 極性

| | BCLK レベル |
|-|---|
| CS 非アサート（アイドル） | HIGH（74HC4040 Q3=0 → 反転 → HIGH） |
| バイト転送中 | LOW |
| バイト完了時（8 クロック後） | HIGH（74HC4040 Q3 立ち下がり → 反転 → 立ち上がり）|

74HC595 は BCLK 立ち上がり（= RCLK 立ち上がり）で Q 出力を確定する。

## ファームウェア変更（par_slave.pio）

BCLK の極性反転に合わせて、スタートアップ同期とメインループの wait 命令のロジックを変更した。

### 変更前（74HC4094 構成）

```asm
    wait 0 gpio PAR_BCLK_PIN    ; スタートアップ同期：BCLK が LOW になるまで待つ
.wrap_target
    wait 1 gpio PAR_BCLK_PIN    ; BCLK 立ち上がり待ち（バイト転送中）
    wait 0 gpio PAR_BCLK_PIN    ; BCLK 立ち下がり待ち（バイト完了）
```

### 変更後（74HC595 + 74AHC1G04 構成）

```asm
    wait 1 gpio PAR_BCLK_PIN    ; スタートアップ同期：BCLK が HIGH になるまで待つ
.wrap_target
    wait 0 gpio PAR_BCLK_PIN    ; BCLK LOW 待ち（バイト転送中）
    wait 1 gpio PAR_BCLK_PIN    ; BCLK HIGH 待ち（バイト完了、74HC595 出力確定）
```

## 影響範囲

- `example/pico2_st7789/src/par_slave.pio`
- `example/pico2_ssd1309/src/par_slave.pio`
- `example/pico2_st7789/include/config.h`（コメント）
- `example/pico2_ssd1309/include/config.h`（コメント）
- `example/pico2_st7789/README.md`
- `example/pico2_ssd1309/README.md`

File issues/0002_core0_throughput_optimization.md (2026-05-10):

# Core0 スループット最適化

## 問題

SPI 入力が 60Hz フレームレートの場合に DVI 出力が全面赤になる。
Core0 が DVI スキャンライン生成と SPI リングバッファのドレインを同時に担っており、処理が追いつかないことが原因と判断した。

## 経緯

- 最適化 1〜5 を実施した結果、全面赤は解消しほぼ半分の内容が読み取れる程度まで改善した。
- 最適化 6 を実施した結果、40〜50 FPS 程度まで綺麗に表示できるようになった。
- 60 FPS での動作確認は別途実施予定。

## 実施した最適化

### 1. `fillScanline` — memcpy の排除

**変更前**: `getScanline()` が内部の `scanlineBuf` にデータを書いてポインタを返し、呼び出し側が `memcpy` で DVI バッファにコピーしていた。

**変更後**: `fillScanline(line, dst)` に API を変更し、DVI バッファ `dst` に直接書き込む形にした。これにより `scanlineBuf` の確保・解放も不要になり、メモリも削減できた。

**効果**: 640 × 2 byte × 480 lines × 60 fps ≈ 36 MB/s の SRAM 転送を削減。

### 2. `writePixelRgb565` — ピクセル毎の physIndex() 乗算を排除

**変更前**: RAMWR でのピクセル書き込みごとに `physIndex(ramwrX, ramwrY)` を呼び出していた。この関数は MADCTL の MV/MX/MY に基づく条件分岐 5 本と `py * lcdWidth` の乗算を含んでいた。

**変更後**: MADCTL 確定時（および RAMWR コマンド受信時）に `updateWriteCache()` を呼び、以下の値を事前計算してキャッシュする。

- `cachedBGR`: BGR スワップフラグ
- `cachedLogW` / `cachedLogH`: 論理幅・高さ
- `cachedHStep`: 1 ピクセル書き込むたびに `writePtr` に加算する差分（配列要素数単位）
- `cachedVLineStep`: 論理行の折り返し時に `writePtr` に加算する補正差分
- `writePtr`: 現在の書き込み位置へのポインタ

`writePixelRgb565` の書き込みは `*writePtr = px; writePtr += cachedHStep;` と比較のみになった。

MV/MX/MY 各組み合わせの `cachedHStep` / `cachedVLineStep`:

| MV | MX | MY | hStep  | vLineStep |
|----|----|----|---|---|
| 0  | 0  | 0  | +1 | 0 |
| 0  | 1  | 0  | -1 | +2·W |
| 0  | 0  | 1  | +1 | -2·W |
| 0  | 1  | 1  | -1 | 0 |
| 1  | 0  | 0  | +W | 1 - W·H |
| 1  | 1  | 0  | +W | -1 - W·H |
| 1  | 0  | 1  | -W | 1 + W·H |
| 1  | 1  | 1  | -W | W·H - 1 |

（W = lcdWidth, H = lcdHeight）

**効果**: 240 × 320 × 60 fps ≈ 460 万回/秒の乗算と分岐を加算・比較のみに置き換え。

### 3. 垂直スケーリングの除算を固定小数点乗算に置き換え

**変更前**: `fillScanline` 内でスキャンラインごとに `(offset * lcdH) / displayH` の除算を実行していた。

**変更後**: `calcScaleParams()` で `vStep = (lcdH << 16) / displayH` を事前計算し、実行時は `(offset * vStep) >> 16` の乗算＋シフトに変更した。

### 4. ホットパス関数への `[[gnu::always_inline]]` 付与

`writePixelRgb565` / `feedData` にインライン展開を強制し、関数呼び出しのオーバーヘッドを排除した。

### 5. `inputData` ホットループの再構築

**変更前**: 1 バイトごとに `feedData(byte)` → `switch(currentCmd)` → `processRamwrByte(byte)` → `switch(pixelFormat)` の呼び出し連鎖を繰り返していた。

**変更後**: `currentCmd` と `pixelFormat` の switch をループ外に追い出した。

```
【変更前】
inputData(data, len)
  for i in 0..len-1:
    feedData(data[i])         ← per-byte
      switch(currentCmd)      ← per-byte
        processRamwrByte()    ← per-byte
          switch(pixelFormat) ← per-byte

【変更後】
inputData(data, len)
  feedData(data, len)
    switch(currentCmd)        ← 一度だけ
      CMD_RAMWR →
        processRamwrData(data, len)
          switch(pixelFormat) ← 一度だけ
            タイトループ
```

`processRamwrData` は各ピクセルフォーマットごとに:
1. 前回呼び出しからの端数バイト (`ramwrBuf`) を drain
2. 揃ったバイトをタイトループで一括処理
3. 残った端数バイトを `ramwrBuf` に保存

RGB565 のタイトループ（正常系）:
```cpp
while (i + 2 <= length) {
    writePixelRgb565((data[i] << 8) | data[i + 1]);
    i += 2;
}
```

また、`example/pico2/src/main.cpp` において以下の変更も行った（ユーザーによる）:
- `process_spi_ring_buf()` の予備的な呼び出しを削除し、DVI キューへの応答レイテンシを削減
- `flush_data_batch` のインライン化と `g_sl2d` のヌルチェックを冒頭に集約

**効果**: `switch` の評価をデータバイト数分から 1 回に削減。

### 6. RGB444 / RGB666 の直接 RGB565 パック

**変更前**: `writePixel(r8, g8, b8)` を経由していたため、4→8bit / 6→8bit への無駄な展開が発生していた。また `writePixel` 内と `writePixelRgb565` 内の BGR swap が打ち消し合い、RGB444/666 では BGR モードが実質無効になっていた（バグ）。

**変更後**: `writePixel` を削除し、`processRamwrData` から `writePixelRgb565` を直接呼ぶ。

RGB444（4bit チャンネル）から RGB565 への直接変換:
- R5/B5: `(x<<1)|(x>>3)` (上位ビット繰り返し)
- G6: `(x<<2)|(x>>2)` (上位 2bit 繰り返し)

RGB666（各バイト上位 6bit 有効）から RGB565 への直接変換:
- `(byte0 & 0xF8) << 8 | (byte1 & 0xFC) << 3 | byte2 >> 3` の 1 式で完結

**挙動の変化（意図的）**: RGB444/666 で BGR モードが正しく機能するようになった。

## 変更ファイル

- `lib/include/spilcd2dvi/spilcd2dvi.hpp`: `getScanline` → `fillScanline(line, dst)` に API 変更
- `lib/src/spilcd2dvi.cpp`: 上記最適化の実装
- `example/pico2/src/main.cpp`: `fillScanline` への呼び出し変更、`process_spi_ring_buf` の改善

## 検証

実機では 40〜50 FPS 程度まで綺麗に表示できることを確認。60 FPS での動作確認は別途実施予定。

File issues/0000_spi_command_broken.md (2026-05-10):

# SPI コマンドが誤って解釈される

## 現象

SPI スレーブから受信したコマンドが正しく解釈されない。

- SPI から映像を入力しても、初期のカラーバー表示から変化しない。
- 数秒～数十秒に1回、画面(カラーバー)の明暗が反転する。恐らく入力されたコマンドが INVON / INVOFF コマンドと誤って解釈されている。

## 解析状況

- 試しに main.cpp の `g_sl2d->inputCommand(byte)` を `g_sl2d->inputCommand(0x2C)` に書き換えて全てのコマンドを RAMWR として解釈するようにしたところ、色は化けているものの、SPI から入力した像が表示さた。色の化け方は試すたびに変わる。十数回に1回程度、正しい色で表示されるように見えることもある。
    - SPI のバイト単位の同期が取れてない？

## 対応

解析が難航したため、Pico2 の外部で SPI 入力をパラレルに変換する方針にした結果問題は無くなった。

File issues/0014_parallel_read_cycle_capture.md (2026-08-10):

# 0014: パラレル I/F でホストのリードサイクルがコマンドとして混入する

## 現象

pico2w_remote + パラレル I/F (SC1602/SC2004, 6800 バス, R/W→CS・E→WR 接続) で、
実機 LCD は正常に表示されるのに LcdTap 側では文字抜け・化け・CGRAM グリフの崩れが
発生した。Statistics では RX Drop / Overflow は 0 のまま Unknown Commands が徐々に
増加 (Last Unknown Command=0x00)。WiFi を無効化すると大幅に改善するが完全には
消えない。pico2_universal では発生しない。オシロで CS/WR/DC の波形に乱れはない。

Command Dump を pico2_universal と比較すると、DC=0 の余計なバイトが散発的に挿入
されており、値は 0x10→0x12→0x13→… や 0x43→0x47→…→0x50 のような単調増加、
または同一値の繰り返しだった。

## 原因

挿入バイトの正体は、ホストがコマンド/データ書き込みごとに行う **ビジーフラグ
ポーリング (RW=1, RS=0 のリードサイクル) の応答 (BF | アドレスカウンタ)** だった。
AC は書き込みのたびに増えるため単調増加になり、DDRAM 1 行目 (0x00–0x13)・
2 行目 (0x40–0x53) のアドレス範囲と観測値が一致する。

R/W→CS 接続でのリード除去は「CS (=R/W) 立ち上がりの GPIO IRQ で
`spiSlaveResetSm()` を呼び、SM をプログラム先頭の `wait 0 gpio PAR_CS_PIN` に
戻す」ことで実現されていたが、これは割り込みレイテンシ頼みの競合だった。ホストは
R/W を上げてから約 2 µs 後にリードの E 立ち下がり (= サンプル点) を発生させるため、
IRQ→SM リセットが 2 µs を超えるとリード応答がキャプチャされる。

pico2w_remote では Core 0 が cyw43/lwIP/USB CDC のフラッシュ常駐コードを高頻度で
実行するため、XIP キャッシュミスとコア間フラッシュアービトレーションで Core 1 の
IRQ 経路 (SDK の GPIO ディスパッチと `spiSlaveResetSm` 自体がフラッシュ上) の
レイテンシが µs オーダーに伸びるスパイクが発生し、競合に負けてリードバイトが
混入した。WiFi ON で頻発・OFF で残留・pico2_universal では発生しない、という
観測はすべてこの XIP 競合の度合いで説明できる。

混入した BF|AC バイトはコマンドとして実行され、各症状を引き起こす:

- 0x40–0x7F → Set CGRAM Address → 後続データが CGRAM を破壊 (グリフ崩れ)
- 0x80– (BF=1 時) → Set DDRAM Address → カーソル移動 (文字抜け・位置ずれ)
- 0x10–0x1F → Cursor/Display Shift → 表示ずれ
- 0x00 (AC=0 時) → Unknown Command 0x00

## 対処

リード除去を IRQ から PIO プログラム内のレベル判定に移し、競合を原理的に排除した。

- `parallel_8bit.pio`: サンプリング (`in pins, 9`) の直後に `jmp pin, drop` を追加。
  EXECCTRL_JMP_PIN = CS (8080: CS#, 6800: R/W) が High なら `mov isr, null` で
  破棄する。判定はサンプルの 1 サイクル後で、ホストは E 立ち下がり後も約 1 µs は
  R/W を保持するため競合しない。トランザクション単位の同期だった先頭の
  `wait 0 gpio PAR_CS_PIN` はバイト単位のゲートで置き換えられたため削除。
- `bus_input.cpp` `parSlaveInit()`: `sm_config_set_jmp_pin(&c, cfg.pinCs)` を追加。
- `bus_input.cpp` `busInputSwitch()`: PARALLEL の CS 立ち上がり IRQ 有効化を削除
  (SPI_3LINE / SPI_4LINE は従来どおり)。
- `spi_slave.cpp` `spiSlaveResetSm()`: `__not_in_flash_func` を付与し、SPI モードで
  残る CS-rise IRQ 経路のレイテンシも XIP 競合の影響を受けにくくした。

8080 ホストに対しても「CS=High のストローブは自分宛でないので捨てる」という意味に
なり、同じロジックで両バススタイルに正しく働く。

## 対象ファイル

- `example/pico2_common/src/parallel_8bit.pio`
- `example/pico2_common/src/bus_input.cpp`
- `example/pico2_common/src/spi_slave.cpp`

## 補足

- CS 立ち上がり IRQ による SM リセットの競合問題は issue 0007 と同根 (割り込み
  レイテンシ頼みの制御は入力ストリームに対して原理的に競合する)。
- ダンプで稀に見られた「抜け」は、IRQ リセットが遅延して次のライトストローブ付近で
  FIFO クリアが走ったケースと考えられ、IRQ 削除により同時に解消される見込み。
- 6800 モードで検証したホスト: `sc1602_test` (RP2040, 全書き込み前に BF ポーリング、
  DDRAM リードバックテストあり)。

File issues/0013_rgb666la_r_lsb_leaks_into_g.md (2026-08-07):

# 0013: RGB666-LA デコードで R チャネルの LSB が G チャネルの MSB に混入する

## 現象

`InterfaceFormat::RGB666_UNPACK_LA8_BE` (ST7789/ILI9341 の COLMOD=0x06、18bpp
アンパック) のとき、ワイヤ上の R チャネル bit0 (byte0 の bit2) が 1 かつ
G チャネル MSB が 0 の画素で、フレームバッファの G 値が +32 (bit10) ずれる。
乱数画像では約 25% の画素に発生する。DVI 出力では G が 1/2 段明るくなる
subtle な色ずれとして現れる。

## 発見の経緯

example/test_pico2 (実機テスト装置) のホスト側閉ループテスト
(`test_host/verify_test.cpp`) で検出。テストパターン生成 → LcdTap 実体への
RAMWR 投入 → getframebuffer 相当のシリアライズ → ストリーミング期待値比較、
という経路で `ST7789 colmod=06` の全回転が不一致率 24.8% で NG となった。
不一致ビットが常に bit10 (G の MSB)、発生率が「R6 LSB=1 かつ G6 MSB=0 の
確率 (1/4)」と一致することから特定。

## 原因

`lib/src/lcdtap.cpp` の `processRamwrDataImpl()` RGB666_UNPACK_LA8_BE ケース:

```cpp
pixel |= (data[i] & 0xFCu) << 8;  // R5
```

`0xFC` は byte0 の bit7:2 (= R6 全 6 bit) を残すため、`<< 8` で
bits15:10 に配置され、RGB565 の R フィールド (bits15:11) から 1 bit
はみ出して G の MSB (bit10) に OR される。コメントの意図
(`R5 = byte0>>3`) どおりなら上位 5 bit のみ残すべき。

同じ式が leftover ドレイン側とタイトループ側の 2 箇所にあった。

## 修正

マスクを `0xF8` に変更し、R6 の上位 5 bit だけを bits15:11 に配置する
(2 箇所)。

```cpp
pixel |= (data[i] & 0xF8u) << 8;  // R5
```

RGB666_UNPACK_RA8_BE 側は `(byte >> 1) & 0x1F` で正しくマスクしており
影響なし。

## 検証

- `example/test_pico2/test_host/verify_test.cpp` の
  `ST7789 colmod=06` / `ILI9341 fmt=RGB666LA` 系ケースが全回転で PASS。
- 既存の `example/pico2_common/test_host/ramwr_test.cpp` は RGB666 を
  カバーしていなかったため回帰なし。

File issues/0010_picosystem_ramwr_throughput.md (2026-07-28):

# PicoSystem 画像乱れ: RAMWR ピクセル処理のランレングス最適化

## 症状

PicoSystem (SPI 62.5 MHz → 外部デシリアライザ → 8bit パラレル、RGB444) で
画像の乱れが発生するようになった。

## 解析

- RGB444 は 1.5 バイト/px のため、同じ 62.5 MHz SPI でもピクセルレートは
  RGB565 より 33% 高い 5.2 Mpx/s になる。
- 従来の `writePixelRgb565()` 経由のループは、`*writePtr` への uint16_t
  ストアが `this` の uint16_t メンバ (cachedInverter / ramwrX / casetXE /
  writePtr) とエイリアス し得るため、コンパイラが毎ピクセル全メンバを
  リロード/ストアするコードを生成していた (約 21〜24 命令/px)。
  BGR / エンディアン分岐のループ外巻き上げは GCC が既に行っており、
  ボトルネックではなかった。
- リング走査等を含めた Core 0 の入力経路コストは予算 (319.2 MHz 時
  約 61 cycles/px) に対しマージン約 1.5 倍しかなく、OSD 描画・XIP
  フェッチ等のスパイクでリングバッファ (16 KB = 入力 4096 バイト分 =
  524 µs) が溢れて乱れになる。

## 対策

`processRamwrDataImpl` の RGB565_BE / RGB444_HPACK2_H2L_BE の tight loop を
ランレングス方式に置換 (`ramwrRgb565RunImpl` / `ramwrRgb444RunImpl`)。

1. **行単位の run 分割**: `run = casetXE - ramwrX + 1` を先に計算し、内側
   ループから行折り返し判定を排除。書き込み状態 (writePtr / x / inverter)
   をレジスタ常駐化。dirty tracking 時は run を 64px セグメント境界でも
   分割し、従来のセグメント粒度を維持。
2. **2px ペア 32bit ストア**: `hStep == +1` のとき 2 ピクセルを 1 つの
   32bit `str` に融合。RGB565 は先頭 1px の peel でアライン。RGB444 は
   ペア区切りがストリーム側で固定のため、非整列時はスカラーループに
   フォールバック。
3. **RGB444 pending キャリー**: 行折り返しが 3 バイトグループの中央に
   落ちる場合 (CASET 幅が奇数)、px0 で行を閉じ px1 を次 run の先頭に
   持ち越す。総ピクセル数は偶数なのでキャリーは必ず消費される。
4. **stride のテンプレート化**: 入力ストライド (1 = パック済み、
   4 = PIO リングワード、その他 = 汎用) をテンプレート引数化。
5. **SRAM 常駐化**: GCC はテンプレート実体化で section 属性を無警告で
   無視する (GCC PR 70435) ため、テンプレート本体を always_inline にし、
   RP2350 の全入力ドライバが使う stride=4 の組み合わせのみ非テンプレート
   関数 (`ramwrRgb565RunRing` 等 4 つ) に stamp して `LCDTAP_RAM_FUNC` を
   付与。SRAM コスト約 3.9 KB。

## 結果

実機 ELF の逆アセンブル実測:

| パス | 変更前 | 変更後 |
|---|---|---|
| RGB565_BE 内側ループ | 約 24 命令/px | 12 命令/2px |
| RGB444 内側ループ | 約 21〜22 命令/px | 23 命令/2px |

PicoSystem 実機で乱れの解消を確認。

## テスト

`example/pico2_common/test_host/ramwr_test.cpp` を追加。独立した参照モデル
とのフレームバッファ全画素比較を、22 シナリオ (MADCTL 8 方位・BGR・LE・
反転・奇数/非整列/1px ウィンドウ・ウィンドウ周回・奇数幅バッファ) ×
チャンク 7 種 × stride 3 種 × dirty 有無で実施。既存の dirty_test /
displaylink_span_test も全パス。

注: MV=1 でも CASET は常に論理 X 軸を駆動する (issue #0009)。テストの
参照モデルで当初これを取り違えて FAIL したが、ライブラリ側は正しい。

## 変更ファイル

- `lib/src/controller_base.hpp`
- `lib/src/lcdtap.cpp`
- `example/pico2_common/test_host/ramwr_test.cpp` (新規)

## 残件

- ESP32 (m5tab5) は RGB565 経路が新実装に切り替わる (RGB444 は ESP 専用
  ブロックを温存) ため、実機での再確認が必要。
- さらにマージンが必要な場合: spi_slave.cpp のリング走査ワードバッチ化、
  `SPI_RING_BUF_LOG2` 14→16 の拡大。

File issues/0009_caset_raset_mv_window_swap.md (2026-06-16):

# 0009: MV=1 時の CASET/RASET ウィンドウ X/Y 反転と範囲クリッピング誤り

## 症状

ST7789 / SSD1331 で MV=1 (行列交換モード) を設定した状態でピクセルを書き込むと
画像が崩れる。特に非正方形パネルで顕著。

## 原因

### CASET/RASET (ST7789) および SETCOLUMN/SETROW (SSD1331) の処理

issue #0008 の修正で `hwColStart/End` / `hwRowStart/End` フィールドと
`updateWriteCache()` 内の MV 対応スワップが追加された。
しかし CASET/RASET・SETCOLUMN/SETROW のハンドラは MV フラグに関わらず
常に hwCol / hwRow に固定で書き込んでいた。

`updateWriteCache()` MV=1 の動作:

```
casetXS = hwRowStart   // 論理 X (fast axis)
rasetYS = hwColStart   // 論理 Y (slow axis)
```

ホストドライバは **CASET を論理 X、RASET を論理 Y** として送る。
それにもかかわらず、ハンドラが CASET→hwCol、RASET→hwRow に格納するため:

- `casetXS` = hwRowStart = **RASET の値** → X に RASET 値が入る (誤り)
- `rasetYS` = hwColStart = **CASET の値** → Y に CASET 値が入る (誤り)

### クリッピング範囲の誤り

MV=1 のとき論理 X は lcdHeight 方向、論理 Y は lcdWidth 方向にマップされる。
しかし修正前は常に:

- CASET → `lcdWidth - 1` でクリップ (誤り。MV=1 では `lcdHeight - 1` が正しい)
- RASET → `lcdHeight - 1` でクリップ (誤り。MV=1 では `lcdWidth - 1` が正しい)

例: ST7789 (320×240 landscape, MV=1)
- ホストは CASET で 0〜319 を送るが `lcdWidth-1=239` でクリップ → 240〜319 が失われる

## 修正

### 修正方針

CASET/RASET および SETCOLUMN/SETROW のハンドラを MV フラグで分岐し、
格納先と上限値を切り替える。

| MV | コマンド | 格納先 | 上限 |
|----|---|---|---|
| 0 | CASET / SETCOLUMN | hwColStart/End | lcdWidth - 1  |
| 0 | RASET / SETROW | hwRowStart/End | lcdHeight - 1 |
| 1 | CASET / SETCOLUMN | hwRowStart/End | lcdHeight - 1 |
| 1 | RASET / SETROW | hwColStart/End | lcdWidth - 1  |

`updateWriteCache()` MV=1 のとき `casetXS = hwRowStart`、`rasetYS = hwColStart`
となるため、上記の格納先で CASET 値が論理 X、RASET 値が論理 Y に正しくマップされる。

### 変更ファイル

- `lib/src/st7789_controller.cpp`: `CMD_CASET` / `CMD_RASET` ハンドラを MV で分岐
- `lib/src/ssd1331_controller.cpp`: `CMD_SETCOLUMN` / `CMD_SETROW` ハンドラを MV で分岐

### SSD1306 への影響

SSD1306 には MV 相当ビットがなく `updateWriteCache()` も固定実装のため、
本バグの影響を受けない。

## 影響範囲

| コントローラ | 影響 |
|---|---|
| ST7789  | MADCTL MV=1 時に描画ウィンドウ X/Y が反転し画像崩れ → **修正済み** |
| SSD1331 | SETREMAP REMAP_ADDR_INC=1 時に同様の画像崩れ → **修正済み** |
| SSD1306 | MV 相当ビットなし → **影響なし** |

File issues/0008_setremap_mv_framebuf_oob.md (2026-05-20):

# 0008: SETREMAP/MADCTL MV=1 設定後のフレームバッファ境界外書き込み

## 症状

SSD1331 で `display.setRotation(1)` を呼び出した後に `display.show()` などで
ピクセルデータを送信すると LcdTap が panic する (Pico ハードフォルト)。

- `setRotation(1)` のみ: 問題なし
- `setRotation(1)` + ピクセルデータ: 必ず panic

ST7789 でも MADCTL に MV ビット (bit 5) が立った状態で RAMWR を送ると
同様の境界外書き込みが発生する可能性がある。

## 原因

### コントローラ共通の設計

`writePixelRgb565()` はフレームバッファ書き込み位置を以下の式で管理する:

```
physIndex(lcol, lrow) = lcol * cachedHStep + cachedHOffset
                      + lrow * cachedVStep + cachedVOffset
```

`SETREMAP(REMAP_ADDR_INC=1)` / `MADCTL(MV=1)` が設定されると **縦方向アドレスインクリメント**
モードになり、ステップ値が入れ替わる:

| モード | cachedHStep | cachedVStep |
|---|---|---|
| mv=0 (横) | ±1 | ±lcdWidth |
| mv=1 (縦) | ±lcdWidth | ±1 |

### バグの発生

`SETCOLUMN` / `CASET` は常にハードウェアカラム座標 (col 0..lcdWidth-1) を送ってくるが、
`casetXS/XE` にそのまま格納され、`physIndex()` のロジカル X として使われていた。

mv=1 のとき `cachedHStep = lcdWidth` なので:

```
physIndex(x = casetXE, y = 0)
  = casetXE × lcdWidth + ...
```

例: SSD1331 (96×64), SETCOLUMN(0,95), SETREMAP(REMAP_ADDR_INC=1)

```
physIndex(95, 0) = 95 × 96 = 9120
framebuf サイズ   = 96 × 64 = 6144  → 境界外!
```

例: ST7789 (320×240 landscape), CASET(0,319), MADCTL(MV=1)

```
physIndex(319, 0) = 319 × 320 = 102080
framebuf サイズ   = 320 × 240 = 76800  → 境界外!
```

## 修正 (commit: TBD)

### 修正方針

`SETCOLUMN` / `CASET` および `SETROW` / `RASET` の値を**ハードウェア座標**として
別フィールド (`hwColStart/End`, `hwRowStart/End`) に保存し、
`updateWriteCache()` 内で mv フラグに応じてロジカル座標に変換してから
`casetXS/XE` / `rasetYS/YE` に格納する。

| mv | ロジカル X (fast axis) | ロジカル Y (slow axis) |
|----|---|---|
| 0  | ハードウェア col | ハードウェア row |
| 1  | ハードウェア row | ハードウェア col |

### 検証

mv=1, mx=0, my=0 のとき:
- `cachedHStep = lcdWidth`, `cachedVStep = 1`
- `physIndex(hwRow, hwCol) = hwRow × lcdWidth + hwCol`
- 最大値: `physIndex(lcdHeight-1, lcdWidth-1) = (lcdHeight-1) × lcdWidth + (lcdWidth-1) = lcdWidth × lcdHeight - 1` ✓

### 変更ファイル

- `lib/src/ssd1331_controller.hpp` / `.cpp`: `hwColStart/End`, `hwRowStart/End` 追加
- `lib/src/st7789_controller.hpp` / `.cpp`: 同上 (ST7789 は RAMWR ハンドラも変更)

### ST7789 RAMWR ハンドラの変更

ST7789 は `dispatchCommand(CMD_RAMWR)` で `ramwrX = casetXS` を設定してから
`updateWriteCache()` を呼んでいたため、casetXS がハードウェア座標のまま
ramwrX に入ってしまっていた。修正後は `updateWriteCache()` を先に呼んで
hw→logical 変換を済ませてから `ramwrX = casetXS` を設定する。

## 影響範囲

| コントローラ | 影響 |
|---|---|
| SSD1331 | SETREMAP REMAP_ADDR_INC=1 設定後に panic → **修正済み** |
| ST7789  | MADCTL MV=1 かつ lcdWidth > lcdHeight のとき境界外書き込み → **修正済み** |
| SSD1306 | `cachedHStep` 固定値 1、MV 相当ビットなし → **影響なし** |

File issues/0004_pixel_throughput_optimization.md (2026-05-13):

# ピクセル処理スループット最適化

コミット: f0efa2897d22f265cd531905dffbb94c0b92c8c9

## 概要

クロック高速化（最大 62.5 MHz）に伴ってピクセル処理のスループットが不足したため、
以下の 2 点の最適化を実施した。

## 最適化 1: RGB444 ビット変換の簡略化

### 変更前

`writePixel(r8, g8, b8)` を経由して変換していた（4→8bit 展開を挟む）か、
あるいは以下の MSB 繰り返し方式を使用していた。

```
R5 = (r4 << 1) | (r4 >> 3)   // 5bit: 上位ビット繰り返し
G6 = (g4 << 2) | (g4 >> 2)   // 6bit: 上位 2bit 繰り返し
B5 = (b4 << 1) | (b4 >> 3)   // 5bit: 上位ビット繰り返し
```

この方式はチャンネルあたり 2 演算（シフト + OR）が必要だった。

### 変更後

`writePixelRgb565` を直接呼び出し、1 演算（シフト）で RGB565 フィールドに MSB アラインする
方式に変更した。

```cpp
// byte0: R1[3:0] G1[3:0]  byte1: B1[3:0] R2[3:0]  byte2: G2[3:0] B2[3:0]
// 4bit→5bit: x<<1 (MSB-align; LSB zeroed)
// 4bit→6bit: x<<2 (MSB-align; lower 2 bits zeroed)
pixel0 |= (b0 << 8) & 0xF000;  // R1[3:0] → RGB565 bits[15:12]
pixel0 |= (b0 << 7) & 0x0780;  // G1[3:0] → RGB565 bits[10:7]
pixel0 |= (b1 >> 3) & 0x001E;  // B1[3:0] → RGB565 bits[4:1]
```

変換誤差: 最大 1 LSB（値 0 → 0、値 15 → 30/62 ではなく最大値の 31/63 にならない）。
輝度精度より演算速度を優先した。

### 変更ファイル

- `lib/src/lcdtap.cpp`

## 最適化 2: ST7789 サンプルで DMA リングバッファを直接 inputData に渡す

### 変更前

SPI リングバッファから各バイトを取り出して別の中間バッファ（`dataBatch[]`）にコピーし、
その後 `inputData(dataBatch, len, 1)` を呼ぶ形だった。

### 変更後

中間バッファを廃止し、リングバッファのポインタを直接 `inputData` に渡す。
`inputData` の `stride` 引数に `sizeof(uint32_t)` を指定することで、
各 32bit ワードの低バイト（SPI データバイト）だけを読み飛ばしながら処理できるようにした。

```cpp
// コマンドバイトが来るたびに、それまでのデータ範囲を一括して渡す
gInst->inputData((uint8_t *)&spiRingBuf[dataStart], dataLen, sizeof(uint32_t));
```

リングバッファの各ワード: `[bit8: DCX, bits7:0: data byte]`
（上位 3 バイトは 0 またはフラグのみのため stride=4 で低バイトのみ読み取れる）

### 変更ファイル

- `example/pico2_st7789/src/main.cpp`

## 結果

40〜50 FPS 以上での安定動作を確認。

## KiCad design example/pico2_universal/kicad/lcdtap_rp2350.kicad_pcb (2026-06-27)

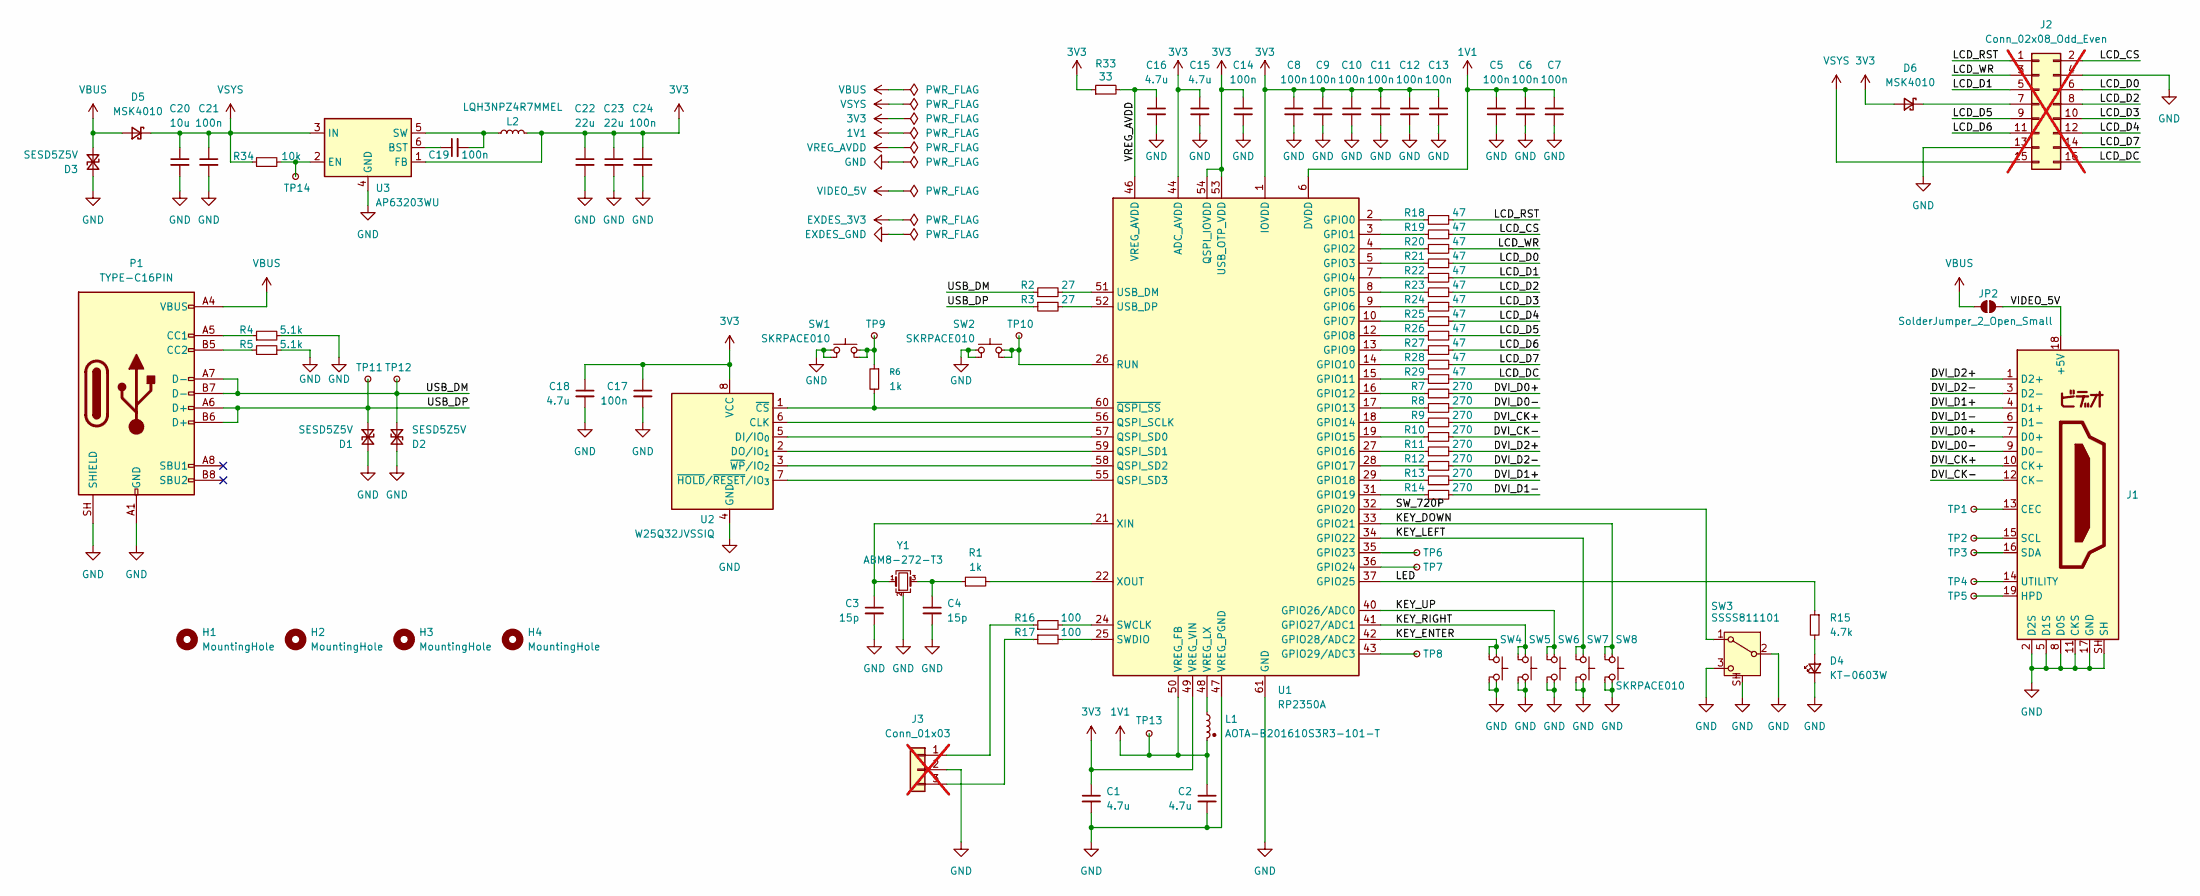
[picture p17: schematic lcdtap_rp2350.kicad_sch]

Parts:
C1, C2, C15, C16, C18: 4.7u; C_0603_1608Metric; LCSC C19666
C3, C4: 15p; C_0402_1005Metric; LCSC C1548
C5, C6, C7, C8, C9, C10, C11, C12, C13, C14, C17, C19, C21, C24: 100n; C_0402_1005Metric; LCSC C1525
C20: 10u; C_0603_1608Metric; LCSC C19702
C22, C23: 22u; C_0603_1608Metric; LCSC C59461
D1, D2, D3: SESD5Z5V; D_SOD-523; LCSC C19631222
D4: KT-0603W; LED_0603_1608Metric; LCSC C2290
D5, D6: MSK4010; D_SOD-523; LCSC C282563
H1, H2, H3, H4: MountingHole; MountingHole_3.5mm
J1: HDMI-001S; HDMI_A_Molex_208658-1001_Horizontal_Edge; LCSC C720616
J2: Conn_02x08_Odd_Even; PinHeader_2x08_P2.54mm_Horizontal_Rev; not fitted
J3: Conn_01x03; PinHeader_1x03_P2.54mm_Vertical; not fitted
JP2: SolderJumper_2_Open_Small; SolderJumper-2_P1.3mm_Open_RoundedPad1.0x1.5mm
L1: AOTA-B201610S3R3-101-T; LCSC C42411119
L2: LQH3NPZ4R7MMEL; LCSC C527613
P1: TYPE-C16PIN; USB_C_Receptacle_HCTL_HC-TYPE-C-16P-01A; LCSC C393939
R1, R6: 1k; R_0402_1005Metric; LCSC C11702
R2, R3: 27; R_0402_1005Metric; LCSC C25100
R4, R5: 5.1k; R_0402_1005Metric; LCSC C25905
R7, R8, R9, R10, R11, R12, R13, R14: 270; R_0402_1005Metric; LCSC C25155
R15: 4.7k; R_0402_1005Metric; LCSC C25900
R16, R17: 100; R_0402_1005Metric; LCSC C25076
R18, R19, R20, R21, R22, R23, R24, R25, R26, R27, R28, R29: 47; R_0402_1005Metric; LCSC C25118
R33: 33; R_0402_1005Metric; LCSC C25105
R34: 10k; R_0402_1005Metric; LCSC C25744
SW1, SW2, SW4, SW5, SW6, SW7, SW8: SKRPACE010; SW_Push_1P1T_NO_Vertical_Wuerth_434133025816; LCSC C139797
SW3: SSSS811101; SW_SPDT_Alps_SSSS811101; LCSC C109335
TP1, TP2, TP3, TP4, TP5, TP6, TP7, TP8, TP9, TP10, TP11, TP12, TP13, TP14: TestPoint_Small; TestPoint_Pad_D1.0mm
U1: RP2350A; QFN-60-1EP_7x7mm_P0.4mm_EP3.4x3.4mm; LCSC C42411118
U2: W25Q32JVSSIQ; SOIC-8_5.3x5.3mm_P1.27mm; LCSC C179173
U3: AP63203WU; TSOT-23-6; LCSC C780769
Y1: ABM8-272-T3; Crystal_SMD_3225-4Pin_3.2x2.5mm; LCSC C20625731

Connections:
1V1: C2.1, C5.1, C6.1, C7.1, L1.1, TP13.1 (1_1), U1.6 (DVDD), U1.23 (DVDD), U1.39 (DVDD), U1.50 (VREG_FB)
3V3: C1.1, C8.1, C9.1, C10.1, C11.1, C12.1, C13.1, C14.1, C15.1, C17.1, C18.1, C22.1, C23.1, C24.1, D6.2 (A), L2.1, R33.1, U1.1 (IOVDD), U1.11 (IOVDD), U1.20 (IOVDD), U1.30 (IOVDD), U1.38 (IOVDD), U1.44 (ADC_AVDD), U1.45 (IOVDD), U1.49 (VREG_VIN), U1.53 (USB_OTP_VDD), U1.54 (QSPI_IOVDD), U2.8 (VCC), U3.1 (FB)
/DVI_CK+: J1.10 (CK+), R9.2
/DVI_CK-: J1.12 (CK-), R10.2
/DVI_D0+: J1.7 (D0+), R7.2
/DVI_D0-: J1.9 (D0-), R8.2
/DVI_D1+: J1.4 (D1+), R13.2
/DVI_D1-: J1.6 (D1-), R14.2
/DVI_D2+: J1.1 (D2+), R11.2
/DVI_D2-: J1.3 (D2-), R12.2
/KEY_DOWN: SW8.2, U1.33 (GPIO21)
/KEY_ENTER: SW4.2, U1.42 (GPIO28/ADC2)
/KEY_LEFT: SW7.2, U1.34 (GPIO22)
/KEY_RIGHT: SW5.2, U1.41 (GPIO27/ADC1)
/KEY_UP: SW6.2, U1.40 (GPIO26/ADC0)
/LCD_CS: J2.2, R19.2
/LCD_D0: J2.6, R21.2
/LCD_D1: J2.5, R22.2
/LCD_D2: J2.8, R23.2
/LCD_D3: J2.10, R24.2
/LCD_D4: J2.12, R25.2
/LCD_D5: J2.9, R26.2
/LCD_D6: J2.11, R27.2
/LCD_D7: J2.14, R28.2
/LCD_DC: J2.16, R29.2
/LCD_RST: J2.1, R18.2
/LCD_WR: J2.3, R20.2
/LED: R15.1, U1.37 (GPIO25)
/SW_720P: SW3.1 (A), U1.32 (GPIO20)
/USB_DM: D2.1 (A1), P1.A7 (D-), P1.B7 (D-), R2.1, TP12.1 (1_1)
/USB_DP: D1.1 (A1), P1.A6 (D+), P1.B6 (D+), R3.1, TP11.1 (1_1)
GND: C1.2, C2.2, C3.2, C4.2, C5.2, C6.2, C7.2, C8.2, C9.2, C10.2, C11.2, C12.2, C13.2, C14.2, C15.2, C16.2, C17.2, C18.2, C20.2, C21.2, C22.2, C23.2, C24.2, D1.2 (A2), D2.2 (A2), D3.2 (A2), D4.1 (K), J1.2 (D2S), J1.5 (D1S), J1.8 (D0S), J1.11 (CKS), J1.17 (GND), J1.SH, J2.4, J2.13, J3.2, P1.A1 (GND), P1.A12 (GND), P1.B1 (GND), P1.B12 (GND), P1.SH (SHIELD), R4.2, R5.1, SW1.1, SW2.1, SW3.2 (B), SW3.3 (C), SW3.SH, SW4.1, SW5.1, SW6.1, SW7.1, SW8.1, U1.47 (VREG_PGND), U1.61 (GND), U2.4 (GND), U3.4 (GND), Y1.2 (G), Y1.4 (G)
unnamed: C4.1, R1.1, Y1.3
unnamed: D4.2 (A), R15.2
unnamed: D6.1 (K), J2.7
unnamed: J1.13 (CEC), TP1.1 (1_1)
unnamed: J1.19 (HPD), TP5.1 (1_1)
unnamed: J1.15 (SCL), TP2.1 (1_1)
unnamed: J1.16 (SDA), TP3.1 (1_1)
unnamed: J1.14 (UTILITY), TP4.1 (1_1)
unnamed: J3.1, R16.1
unnamed: J3.3, R17.1
unnamed: P1.A5 (CC1), R4.1
unnamed: P1.B5 (CC2), R5.2
unnamed: R6.1, SW1.2, TP9.1 (1_1)
unnamed: R18.1, U1.2 (GPIO0)
unnamed: R19.1, U1.3 (GPIO1)
unnamed: R20.1, U1.4 (GPIO2)
unnamed: R21.1, U1.5 (GPIO3)
unnamed: R22.1, U1.7 (GPIO4)
unnamed: R23.1, U1.8 (GPIO5)
unnamed: R24.1, U1.9 (GPIO6)
unnamed: R25.1, U1.10 (GPIO7)
unnamed: R26.1, U1.12 (GPIO8)
unnamed: R27.1, U1.13 (GPIO9)
unnamed: R28.1, U1.14 (GPIO10)
unnamed: R29.1, U1.15 (GPIO11)
unnamed: R7.1, U1.16 (GPIO12)
unnamed: R8.1, U1.17 (GPIO13)
unnamed: R9.1, U1.18 (GPIO14)
unnamed: R10.1, U1.19 (GPIO15)
unnamed: R11.1, U1.27 (GPIO16)
unnamed: R12.1, U1.28 (GPIO17)
unnamed: R13.1, U1.29 (GPIO18)
unnamed: R14.1, U1.31 (GPIO19)
unnamed: TP6.1 (1_1), U1.35 (GPIO23)
unnamed: TP7.1 (1_1), U1.36 (GPIO24)
unnamed: TP8.1 (1_1), U1.43 (GPIO29/ADC3)
unnamed: U1.56 (QSPI_SCLK), U2.6 (CLK)
unnamed: U1.57 (QSPI_SD0), U2.5 (DI/IO_{0})
unnamed: U1.59 (QSPI_SD1), U2.2 (DO/IO_{1})
unnamed: U1.58 (QSPI_SD2), U2.3 (~WP/IO_{2})
unnamed: U1.55 (QSPI_SD3), U2.7 (~HOLD/~RESET/IO_{3})
unnamed: SW2.2, TP10.1 (1_1), U1.26 (RUN)
unnamed: R16.2, U1.24 (SWCLK)
unnamed: R17.2, U1.25 (SWDIO)
unnamed: R2.2, U1.51 (USB_DM)
unnamed: R3.2, U1.52 (USB_DP)
unnamed: L1.2, U1.48 (VREG_LX)
unnamed: C3.1, U1.21 (XIN), Y1.1
unnamed: R1.2, U1.22 (XOUT)
unnamed: R6.2, U1.60 (~QSPI_SS), U2.1 (~CS)
unnamed: C19.1, U3.6 (BST)
unnamed: R34.2, TP14.1 (1_1), U3.2 (EN)
unnamed: C19.2, L2.2, U3.5 (SW)
VBUS: D3.1 (A1), D5.2 (A), JP2.1 (A), P1.A4 (VBUS), P1.A9 (VBUS), P1.B4 (VBUS), P1.B9 (VBUS)
VIDEO_5V: J1.18 (+5V), JP2.2 (B)
VREG_AVDD: C16.1, R33.2, U1.46 (VREG_AVDD)
VSYS: C20.1, C21.1, D5.1 (K), J2.15, R34.1, U3.3 (IN)

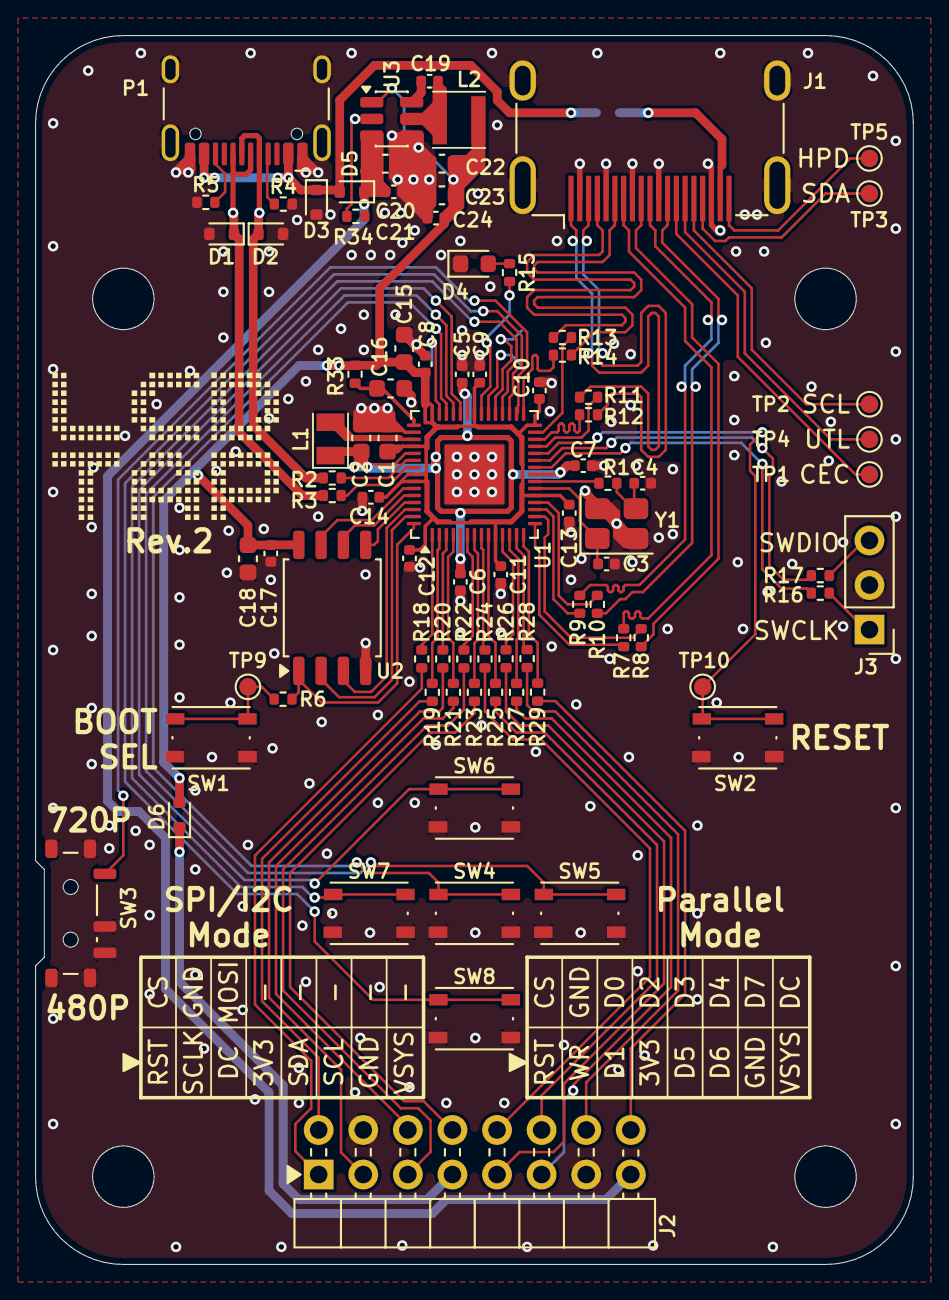
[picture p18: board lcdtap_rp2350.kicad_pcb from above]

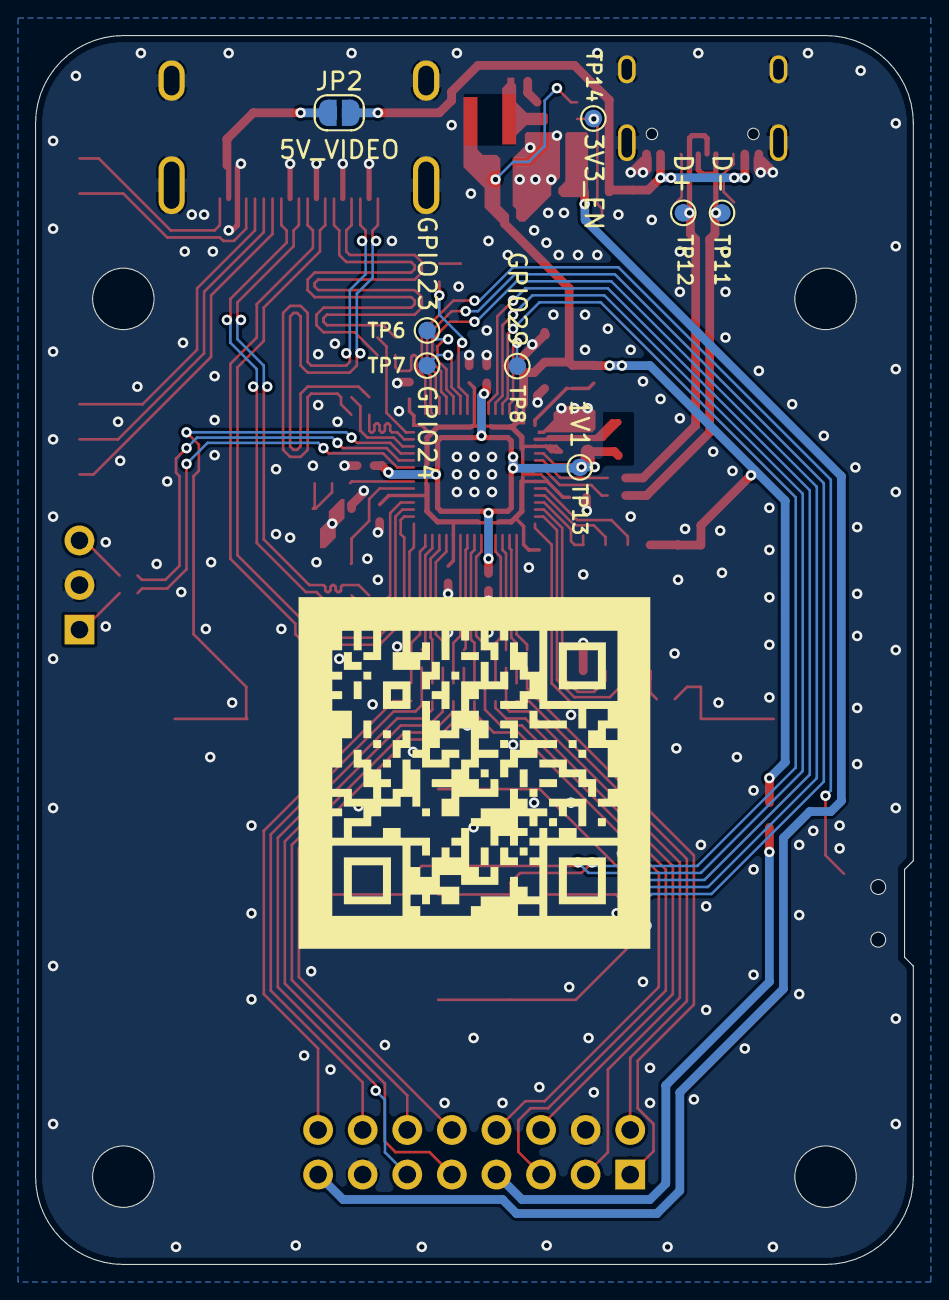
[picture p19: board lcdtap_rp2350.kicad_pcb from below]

Board: 2 copper layers, 50.0 x 70.0 mm, 98 parts (8 on the bottom side), 89 nets.

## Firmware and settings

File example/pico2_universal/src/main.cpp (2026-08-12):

#include <cstdint>
#include <cstdlib>
#include <cstring>
#include <initializer_list>

#include "hardware/gpio.h"
#include "hardware/watchdog.h"
#include "pico/stdlib.h"

#include "lcdtap/lcdtap.hpp"
#include "lcdtap/osd.hpp"
#include "lcdtap/pico2/bus_input.hpp"
#include "lcdtap/pico2/composite_out.hpp"
#include "lcdtap/pico2/hstx_out.hpp"
#include "lcdtap/pico2/i2c_slave.hpp"
#include "lcdtap/pico2/spi_slave.hpp"

#include "composite_dac_kind.hpp"
#include "config.h"
#include "displaylink_out.hpp"
#include "flash_config.hpp"
#include "lcdtap/pico2/splash.hpp"
#include "output_interface.hpp"
#include "parallel_8bit.pio.h"
#include "spi_3line_mode0.pio.h"
#include "splash.hpp"
#include "stats.hpp"
#include "uart_intf.hpp"
#include "video_backend.hpp"

static_assert(PIN_SPI_CS == SPI_CS_PIN,
              "PIN_SPI_CS mismatch with spi_4line_mode0.pio");
static_assert(PIN_SPI_SCLK == SPI_SCLK_PIN,
              "PIN_SPI_SCLK mismatch with spi_4line_mode0.pio");
static_assert(PIN_SPI_MOSI + 1u == PIN_SPI_DC,
              "DC must be MOSI+1 for 'in pins, 2'");
static_assert(PIN_SPI_CS == PAR_CS_PIN,
              "PIN_SPI_CS mismatch with parallel_8bit.pio PAR_CS_PIN");
static_assert(PIN_PAR_CS == PAR_CS_PIN,
              "PIN_PAR_CS mismatch with parallel_8bit.pio PAR_CS_PIN");
static_assert(PIN_PAR_WR == PAR_WR_PIN,
              "PIN_PAR_WR mismatch with parallel_8bit.pio PAR_WR_PIN");
static_assert(PIN_PAR_DC == PIN_PAR_DATA_BASE + 8u,
              "PIN_PAR_DC must be PAR_DATA_BASE+8 for 'in pins, 9'");

// =============================================================================
// Memory pool — used exclusively for the LcdTap framebuffer.
// Always returns the pool start; safe because only one allocation exists at
// a time. poolFree is a no-op: the pool is reused on the next alloc call.
// =============================================================================
static uint8_t memPool[MEM_POOL_SIZE];

static void *poolAlloc(size_t size) {
  size = (size + 3u) & ~3u;
  if (size > sizeof(memPool)) return nullptr;
  return memPool;
}

static void poolFree(void *ptr) { (void)ptr; }

// =============================================================================
// SPI/Parallel ring buffer  (word = [bit8: DCX, bits7:0: data byte])
// DMA alignment constraint: must be aligned to its own byte size.
// =============================================================================
static uint32_t
    __attribute__((aligned(SPI_RING_BUF_BYTES))) spiRingBuf[SPI_RING_BUF_WORDS];

// =============================================================================
// I2C ring buffer  (same word format as SPI ring buffer)
// =============================================================================
static uint32_t i2cRingBuf[I2C_RING_BUF_WORDS];

// =============================================================================
// Interface selection
// =============================================================================
static lcdtap::BusType gCurrentIface = lcdtap::BusType::SPI_4LINE;
static bool gIfaceActive = false;

// =============================================================================
// LcdTap instance
// =============================================================================
static lcdtap::LcdTap *gInst = nullptr;

// OSD instance for runtime configuration
static lcdtap::Osd gOsd;

// =============================================================================
// Module state
// =============================================================================
static lcdtap::pico2::SpiSlaveState gSpi;
static lcdtap::pico2::I2cSlaveState gI2c;
static lcdtap::pico2::HstxOutState gHstx;
static lcdtap::pico2::CompositeOutState gCvbs;
static DisplaylinkOutState gDl;

// =============================================================================
// Video backend selection
// Init keeps its real signatures (see video_backend.hpp); only the
// steady-state operations are dispatched indirectly.
// =============================================================================
static const VideoBackend BACKEND_HSTX = {
    [](void *s) {
      lcdtap::pico2::hstxOutLaunchCore1((lcdtap::pico2::HstxOutState *)s);
    },
    [](void *s) {
      return lcdtap::pico2::hstxOutConsumeNewFrame(
          (lcdtap::pico2::HstxOutState *)s);
    },
    [](void *s) {
      lcdtap::pico2::hstxOutFlashAcquire((lcdtap::pico2::HstxOutState *)s);
    },
    [](void *s) {
      lcdtap::pico2::hstxOutFlashRelease((lcdtap::pico2::HstxOutState *)s);
    },
};

static const VideoBackend BACKEND_COMPOSITE = {
    [](void *s) {
      lcdtap::pico2::compositeOutLaunchCore1(
          (lcdtap::pico2::CompositeOutState *)s);
    },
    [](void *s) {
      return lcdtap::pico2::compositeOutConsumeNewFrame(
          (lcdtap::pico2::CompositeOutState *)s);
    },
    [](void *s) {
      lcdtap::pico2::compositeOutFlashAcquire(
          (lcdtap::pico2::CompositeOutState *)s);
    },
    [](void *s) {
      lcdtap::pico2::compositeOutFlashRelease(
          (lcdtap::pico2::CompositeOutState *)s);
    },
};

static const VideoBackend BACKEND_DISPLAYLINK = {
    [](void *s) { displaylinkOutLaunchCore1((DisplaylinkOutState *)s); },
    [](void *s) {
      return displaylinkOutConsumeNewFrame((DisplaylinkOutState *)s);
    },
    [](void *s) { displaylinkOutFlashAcquire((DisplaylinkOutState *)s); },
    [](void *s) { displaylinkOutFlashRelease((DisplaylinkOutState *)s); },
};

static const VideoBackend *gVideo = &BACKEND_HSTX;
static void *gVideoState = &gHstx;

// Currently active output interface and composite DAC (mirror ConfigFile).
static OutputInterface gOutputIf = OutputInterface::DVI_D;
static CompositeDacKind gCvbsDac = CompositeDacKind::PWM;

// =============================================================================
// OSD user items
// =============================================================================

// User item IDs must be >= OSD_USER_ITEM_ID_BASE so they never collide with
// the library's system items.
static constexpr uint16_t OSD_ITEM_ID_OUTPUT_IF =
    lcdtap::OSD_USER_ITEM_ID_BASE + 0u;
static constexpr uint16_t OSD_ITEM_ID_CVBS_DAC =
    lcdtap::OSD_USER_ITEM_ID_BASE + 1u;

static void onOsdMenuOpen(lcdtap::Osd *osd, void * /*userData*/) {
  // Called after initMenuItems() has populated every system item, so Apply
  // already exists and can be used as an anchor.
  const int16_t busKeyId = lcdtap::OSD_ITEM_ID_SYS_BASE +
                           static_cast<int16_t>(lcdtap::Configs::BUS_INTERFACE);

  lcdtap::OsdMenuItem out = {};
  out.id = OSD_ITEM_ID_OUTPUT_IF;
  out.isAction = false;
  out.config.type = lcdtap::ValueType::ENUM;
  out.config.name = "Output Interface";
  out.config.unit = "";
  out.config.options = OUTPUT_INTERFACE_NAMES;
  out.config.min = 0;
  out.config.max = OUTPUT_INTERFACE_COUNT - 1;
  out.config.step = 1;
  out.config.value = static_cast<int16_t>(gOutputIf);
  // enableKeyId is auto-offset from Configs to OSD id only for system items
  // (osd.cpp initMenuItems), so a user item must supply a resolved id.
  // Composite needs pins the parallel bus already owns.
  out.config.enableKeyId = busKeyId;
  out.config.enableKeyValueMin = static_cast<int16_t>(lcdtap::BusType::I2C);
  out.config.enableKeyValueMax =
      static_cast<int16_t>(lcdtap::BusType::SPI_3LINE);
  // insertItem() does not run updateItemEnables(), so seed isEnabled here.
  out.isEnabled = (gCurrentIface < lcdtap::BusType::PARALLEL);

  lcdtap::OsdMenuItem dac = {};
  dac.id = OSD_ITEM_ID_CVBS_DAC;
  dac.isAction = false;
  dac.config.type = lcdtap::ValueType::ENUM;
  dac.config.name = "Video DAC Type";
  dac.config.unit = "";
  dac.config.options = COMPOSITE_DAC_KIND_NAMES;
  dac.config.min = 0;
  dac.config.max = COMPOSITE_DAC_KIND_COUNT - 1;
  dac.config.step = 1;
  dac.config.value = static_cast<int16_t>(gCvbsDac);
  // Gated on SPI rather than on the Output item: the library allows one
  // enable key per item, so it gates on the axis where a wrong value is a
  // hardware conflict (the R-2R ladder covers the I2C pins) rather than the
  // axis where it is merely inert (DVI-D). compositeDacSanitize() cleans up
  // the inert case at Apply.
  dac.config.enableKeyId = OSD_ITEM_ID_OUTPUT_IF;
  dac.config.enableKeyValueMin = static_cast<int16_t>(OutputInterface::NTSC);
  dac.config.enableKeyValueMax = static_cast<int16_t>(OutputInterface::PAL);
  dac.isEnabled = compositeDacAllowed(CompositeDacKind::R2R, gCurrentIface);

  // Insert before the anchor setting. The first insert shifts the anchor down
  // by one, so it has to be looked up again for the second. The UART parameter
  // list uses the same anchor, so both orders match.
  uint16_t insertId =
      lcdtap::OSD_ITEM_ID_SYS_BASE + static_cast<int16_t>(HOST_PARAM_ANCHOR);
  osd->insertItem(osd->getItemIndexById(insertId), out);
  osd->insertItem(osd->getItemIndexById(insertId), dac);
}

static bool onOsdActionActivated(lcdtap::Osd *osd,
                                 const lcdtap::OsdMenuItem *item,
                                 lcdtap::LcdTap &lcdtap, void * /*userData*/) {
  return false;
}

// =============================================================================
// Input bus switching context (shared helper in pico2_common)
// =============================================================================
// Mutable: switchInterface() refreshes the I2C slave address and the
// parallel WR# inversion from the live LcdTap config before each switch.
static lcdtap::pico2::BusInputContext gBusCtx = {
    &gSpi,
    &gI2c,
    {i2c0, PIN_I2C_SDA, PIN_I2C_SCL, I2C_SLAVE_ADDR},
    i2cRingBuf,
    I2C_RING_BUF_WORDS,
    PIN_PAR_WR,
    PIN_PAR_DATA_BASE,
    PIN_PAR2CS_CS1,
    /*parWrInvert=*/false,
};

// =============================================================================
// GPIO interrupt handler  (RST pin; CS pin for SPI/Parallel modes)
// =============================================================================
static void __not_in_flash_func(gpioIrqHandler)(uint gpio, uint32_t events) {
  if (gpio == PIN_SPI_CS) {
    if (events & GPIO_IRQ_EDGE_RISE) {
      lcdtap::pico2::spiSlaveResetSm(&gSpi);
    }
  } else if (gpio == PIN_RST && gInst) {
    if (events & GPIO_IRQ_EDGE_FALL) {
      gInst->inputReset(true);
      lcdtap::pico2::spiSlaveResetSm(&gSpi);
    }
    gInst->inputReset(!gpio_get(PIN_RST));
  }
}

// =============================================================================
// Interface switching (teardown current, setup new)
// Also used as a callback from uartIfInit().
// =============================================================================
static void switchInterface(lcdtap::BusType newIface) {
  if (gInst) {
    const lcdtap::LcdTapConfig cfg = gInst->getConfig();
    gBusCtx.i2cCfg.slaveAddr = cfg.i2cSlaveAddr;
    // The ST7032 parallel host is a 6800-style bus (E latches on the falling
    // edge); every other supported controller writes 8080-style.
    gBusCtx.parWrInvert =
        (cfg.controllerFamily == lcdtap::ControllerFamily::ST7032);
  }
  // PARALLEL_2CS repurposes the RST pin as the CS1 input: keep the RST IRQ
  // off across the switch and restore the pin only when it is RST again.
  gpio_set_irq_enabled(PIN_RST, GPIO_IRQ_EDGE_FALL | GPIO_IRQ_EDGE_RISE, false);
  lcdtap::pico2::busInputSwitch(gBusCtx, gInst, &gCurrentIface, &gIfaceActive,
                                newIface);
  if (newIface != lcdtap::BusType::PARALLEL_2CS) {
    gpio_init(PIN_RST);
    gpio_set_dir(PIN_RST, GPIO_IN);
    gpio_pull_up(PIN_RST);
    gpio_set_irq_enabled(PIN_RST, GPIO_IRQ_EDGE_FALL | GPIO_IRQ_EDGE_RISE,
                         true);
  }
}

// =============================================================================
// Flash-safe saveConfig wrapper
// Pauses Core 1 at a safe boundary before the flash write so that Core 1
// cannot access flash-resident code (fillScanline, OSD) during erase/program.
// =============================================================================
static void saveConfigSafe(const ConfigFile &cfg) {
  gVideo->flashAcquire(gVideoState);
  saveConfig(cfg);
  gVideo->flashRelease(gVideoState);
}

// =============================================================================
// Dispatch to the active ring buffer processor
// =============================================================================
static void processInputBuf() {
  lcdtap::pico2::busInputProcess(gBusCtx, gCurrentIface);
}

// =============================================================================
// OSD overlay for Core 1 (called after LcdTap::fillScanline)
// =============================================================================
// SRAM-resident: runs per scanline on Core 1; everything it calls
// (getOutputScreenSize, Osd::fillScanline) is SRAM-resident via
// lcdtap/hot.hpp, keeping the whole per-line fill path off the flash.
static void __not_in_flash_func(universalFillScanline)(uint16_t scanY,
                                                       uint16_t *buf,
                                                       void * /*userData*/) {
  uint16_t screenW, screenH;
  gInst->getOutputScreenSize(&screenW, &screenH);
  uint16_t yStart = (screenH - lcdtap::OSD_HEIGHT) / 2;
  uint16_t yEnd = yStart + lcdtap::OSD_HEIGHT;
  uint16_t xStart = (screenW - lcdtap::OSD_WIDTH) / 2;
  if (yStart <= scanY && scanY < yEnd) {
    gOsd.fillScanline(scanY - yStart, buf + xStart);
  }
}

// =============================================================================
// Read key inputs; returns OSD_KEY_XXX bitmask.
// All keys are active-low with internal pull-ups.
// =============================================================================
static uint8_t readKeys() {
  uint8_t keys = 0;
  if (!gpio_get(PIN_KEY_UP)) keys |= lcdtap::OSD_KEY_UP;
  if (!gpio_get(PIN_KEY_DOWN)) keys |= lcdtap::OSD_KEY_DOWN;
  if (!gpio_get(PIN_KEY_LEFT)) keys |= lcdtap::OSD_KEY_LEFT;
  if (!gpio_get(PIN_KEY_RIGHT)) keys |= lcdtap::OSD_KEY_RIGHT;
  if (!gpio_get(PIN_KEY_ENTER)) keys |= lcdtap::OSD_KEY_ENTER;
  return keys;
}

// =============================================================================
// main
// =============================================================================
int main() {
  // -------------------------------------------------------------------------
  // 1. Read boot-time configuration GPIOs and initialize key inputs
  // -------------------------------------------------------------------------
  for (uint pin :
       {PIN_KEY_UP, PIN_KEY_DOWN, PIN_KEY_LEFT, PIN_KEY_RIGHT, PIN_KEY_ENTER}) {
    gpio_init(pin);
    gpio_set_dir(pin, GPIO_IN);
    gpio_pull_up(pin);
  }

  gpio_init(PIN_CFG_OUT_RESO_SEL);
  gpio_set_dir(PIN_CFG_OUT_RESO_SEL, GPIO_IN);
  gpio_pull_up(PIN_CFG_OUT_RESO_SEL);
  sleep_ms(1);

  const bool dvi720p =
      !gpio_get(PIN_CFG_OUT_RESO_SEL);  // LOW=720p (active-low)

  const uint16_t lcdW = LCDTAP_LCD_SIZE_W;
  const uint16_t lcdH = LCDTAP_LCD_SIZE_H;

  // Right button selects alt 720p timing (319.2 MHz CVT-RB) for monitors
  // that reject the standard 480 MHz timing.
  const struct dvi_timing *timing;
  if (dvi720p) {
    timing = !gpio_get(PIN_KEY_RIGHT) ? &dvi_timing_1280x720p_reduced_30hz_alt
                                      : &dvi_timing_1280x720p_reduced_30hz;
  } else {
    timing = &dvi_timing_640x480p_60hz;
  }

  // -------------------------------------------------------------------------
  // 1b. Read flash config — check for USB mass storage boot mode
  // -------------------------------------------------------------------------
  ConfigFile savedCfg = {};
  bool hasSavedCfg;
  if (!gpio_get(PIN_KEY_LEFT)) {
    // If left key is pressed at boot time, start with default settings
    hasSavedCfg = false;
  } else {
    hasSavedCfg = loadConfig(&savedCfg);
  }

  // -------------------------------------------------------------------------
  // 1c. Resolve the video backend.
  //     Must happen before clock init: NTSC and PAL each need their own
  //     clk_sys so that the sample rate is an exact integer division of it.
  // -------------------------------------------------------------------------
  if (hasSavedCfg) {
    // Sanitize against a config written by an older build, a hand-crafted
    // flash image, or a bus/output combination that is no longer legal.
    gOutputIf = outputInterfaceSanitize(
        static_cast<OutputInterface>(savedCfg.outputInterface),
        savedCfg.libConfig.busInterface);
    gCvbsDac = compositeDacSanitize(
        static_cast<CompositeDacKind>(savedCfg.compositeDac),
        savedCfg.libConfig.busInterface);
  }

  const lcdtap::pico2::CompositeTiming *cvbsTiming = nullptr;
  if (gOutputIf == OutputInterface::NTSC) {
    cvbsTiming = &lcdtap::pico2::COMPOSITE_TIMING_NTSC_J_240P;
  } else if (gOutputIf == OutputInterface::PAL) {
    cvbsTiming = &lcdtap::pico2::COMPOSITE_TIMING_PAL_B_288P;
  }
  const bool displayLink = (gOutputIf == OutputInterface::DISPLAY_LINK);

  // -------------------------------------------------------------------------
  // 2. Clock init
  //    DVI-D : PLL_USB → clk_sys=312MHz; PLL_SYS → clk_hstx=bit_clk/2
  //    NTSC  : PLL_SYS → clk_sys=315.000MHz (÷22 = 4x fsc, exact)
  //    PAL   : PLL_SYS → clk_sys=301.500MHz (÷17 = 4x fsc, +46 ppm)
  //    Composite ignores PIN_CFG_OUT_RESO_SEL and the RIGHT-key timing
  //    override; those only select between DVI-D modes. DisplayLink reuses the
  //    DVI-D clock setup: the PIO USB host needs clk_sys to be a multiple of 12
  //    MHz and 312 MHz qualifies, clk_usb stays at 48 MHz for the CDC
  //    interface, and the (unused) HSTX clock is harmless. PIN_CFG_OUT_RESO_SEL
  //    selects the adapter mode instead: HIGH = 1280x720, LOW = 1920x1080.
  // -------------------------------------------------------------------------
  if (cvbsTiming != nullptr) {
    lcdtap::pico2::compositeOutClockInit(cvbsTiming);
    gVideo = &BACKEND_COMPOSITE;
    gVideoState = &gCvbs;
  } else {
    lcdtap::pico2::hstxOutClockInit(timing);
    if (displayLink) {
      gVideo = &BACKEND_DISPLAYLINK;
      gVideoState = &gDl;
    }
  }

  // -------------------------------------------------------------------------
  // 3. LED
  // -------------------------------------------------------------------------
  gpio_init(PIN_LED);
  gpio_set_dir(PIN_LED, GPIO_OUT);
  gpio_put(PIN_LED, 0);

  // -------------------------------------------------------------------------
  // 4. RST input (pull-up; active low from SPI/Parallel master)
  // -------------------------------------------------------------------------
  gpio_init(PIN_RST);
  gpio_set_dir(PIN_RST, GPIO_IN);
  gpio_pull_up(PIN_RST);

  // Output raster size. The saved dviWidth/dviHeight are always overridden
  // below, so this must follow the selected backend or composite would run
  // with DVI geometry. DisplayLink maps the DVI mode pin to the adapter
  // modes (480p slot -> 720p, 720p slot -> 1080p; 1080p needs DL-165/195
  // and falls back to 720p at connect time otherwise).
  uint32_t outW = cvbsTiming ? (uint32_t)cvbsTiming->hActivePixels
                             : (uint32_t)timing->h_active_pixels;
  uint32_t outH = cvbsTiming ? (uint32_t)cvbsTiming->vActiveLines
                             : (uint32_t)timing->v_active_lines;
  if (displayLink) {
    outW = dvi720p ? 1920u : 1280u;
    outH = dvi720p ? 1080u : 720u;
  }

  // -------------------------------------------------------------------------
  // 6. LcdTap init
  // -------------------------------------------------------------------------
  lcdtap::LcdTapConfig cfg;
  lcdtap::getDefaultConfig(lcdtap::ControllerFamily::ST7789, &cfg);
  cfg.buffWidth = lcdW;
  cfg.buffHeight = lcdH;
  cfg.scaleMode = lcdtap::ScaleMode::FIT;
  cfg.dviWidth = static_cast<uint16_t>(outW);
  cfg.dviHeight = static_cast<uint16_t>(outH);

  if (hasSavedCfg) {
    savedCfg.libConfig.dviWidth = cfg.dviWidth;
    savedCfg.libConfig.dviHeight = cfg.dviHeight;
    cfg = savedCfg.libConfig;
    gCurrentIface = cfg.busInterface;
  }

  lcdtap::HostInterface host;
  host.alloc = poolAlloc;
  host.free = poolFree;
  host.log = nullptr;
  host.userData = nullptr;

  lcdtap::LcdTap inst(cfg, host);
  if (inst.getStatus() != lcdtap::Status::OK) panic("LcdTap init failed");

  gInst = &inst;

  // Show the splash image immediately, before the SPI/I2C master has sent
  // any commands. A real reset (RST) or the master's own SLPOUT/DISPON
  // sequence will naturally take over from here.
  lcdtap::pico2::drawSplash(gInst->getFramebuf(), cfg.buffWidth, cfg.buffHeight,
                            cfg.outputRotation, lcdtap::pico2::splashImage,
                            lcdtap::pico2::SPLASH_WIDTH,
                            lcdtap::pico2::SPLASH_HEIGHT);
  gInst->setDisplayOn(true);

  // -------------------------------------------------------------------------
  // 6b. OSD init
  // -------------------------------------------------------------------------
  lcdtap::OsdConfig osdCfg;
  lcdtap::getDefaultOsdConfig(&osdCfg);
  osdCfg.onMenuOpen = onOsdMenuOpen;
  osdCfg.onActionActivated = onOsdActionActivated;
  osdCfg.getStats = [](lcdtap::StatEntry *out, int maxCount, void *) {
    return statsCollect(out, maxCount);
  };
  osdCfg.onStatsReset = [](void *) { statsReset(); };
  osdCfg.userData = nullptr;
  gOsd.init(osdCfg);

  // -------------------------------------------------------------------------
  // 7. RST interrupt
  // -------------------------------------------------------------------------
  gpio_set_irq_enabled_with_callback(PIN_RST,
                                     GPIO_IRQ_EDGE_FALL | GPIO_IRQ_EDGE_RISE,
                                     /*enabled=*/true, &gpioIrqHandler);
  irq_set_priority(IO_IRQ_BANK0, 0x00);
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

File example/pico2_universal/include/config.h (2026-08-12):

#pragma once

#include <cstdint>

// =============================================================================
// Common pins (all interface modes)
// =============================================================================

// Hardware reset, active low (input, pull-up)
static constexpr uint PIN_RST = 0u;

// =============================================================================
// 4-Line SPI slave pins (spi_4line_mode0.pio, PIO1 SM0)
//
// Direct connection — no external ICs required.
//   RST  → GPIO 0  (hardware reset, active low, pull-up on Pico 2)
//   CS   → GPIO 1  (chip select, active low; must match SPI_CS_PIN in
//                   spi_4line_mode0.pio)
//   SCLK → GPIO 2  (clock, CPOL=0: idle LOW; must match SPI_SCLK_PIN in
//                   spi_4line_mode0.pio)
//   MOSI → GPIO 3  (data MSB first; PIO IN_BASE)
//   DC   → GPIO 4  (D/C# signal; sampled as IN_BASE+1 in spi_4line_mode0.pio)
// =============================================================================

// Chip select, active low (input; must equal SPI_CS_PIN defined in
// spi_4line_mode0.pio = 1)
static constexpr uint PIN_SPI_CS = 1u;

// SPI clock (input; must equal SPI_SCLK_PIN defined in spi_4line_mode0.pio = 2)
static constexpr uint PIN_SPI_SCLK = 2u;

// SPI data (input, PIO IN_BASE)
static constexpr uint PIN_SPI_MOSI = 3u;

// D/C# signal (input, PIO IN_BASE+1; 4-line SPI only)
static constexpr uint PIN_SPI_DC = 4u;

// =============================================================================
// Parallel slave pins (parallel_8bit.pio, PIO1 SM0)
//
// Direct connection — no external ICs required.
//   RST  → GPIO 0   (hardware reset, shared with SPI)
//   CS   → GPIO 1   (chip select, active low; shared with PIN_SPI_CS)
//   WR#  → GPIO 2   (write strobe, active low; must match PAR_WR_PIN)
//   D[0] → GPIO 3   (D[0], PIO IN_BASE)  ... D[7] → GPIO 10
//   DC   → GPIO 11  (D/C# signal; sampled as IN_BASE+8)
// =============================================================================

// Chip select, active low (shared with PIN_SPI_CS; must match PAR_CS_PIN)
static constexpr uint PIN_PAR_CS = 1u;

// Write strobe, active low (must match PAR_WR_PIN defined in parallel_8bit.pio)
static constexpr uint PIN_PAR_WR = 2u;

// D[0..7] (input, PIO IN_BASE; GPIO 3-10)
static constexpr uint PIN_PAR_DATA_BASE = 3u;

// D/C# signal (input, PIO IN_BASE+8 = GPIO 11)
static constexpr uint PIN_PAR_DC = 11u;

// =============================================================================
// Dual-chip-select parallel slave pins (parallel_2cs.pio, PIO1 SM0)
//
// For KS0108-style hosts (two controller chips, high-active CS1
// and CS2). One 74HC00 provides the strobe gating; read cycles (busy-flag
// polling) never strobe:
//   CS1  → GPIO 0   (raw, high active; shared with PIN_RST — no reset input
//                    in this mode, the RST GPIO IRQ must be disabled)
//   CS2  → GPIO 1   (raw, high active; shared with PIN_SPI_CS)
//   /EW  → GPIO 2   (= NAND(E, /R/W), /R/W = NAND(R/W, R/W); LOW only while
//                    E is high in a WRITE cycle; shared with PIN_PAR_WR)
//   D[0] → GPIO 3   ... D[7] → GPIO 10  (shared with the parallel bus)
//   D/I  → GPIO 11  (0 = command, 1 = data; shared with PIN_PAR_DC)
//   /RES   not connected
// =============================================================================

// CS1, high active (shared with PIN_RST)
static constexpr uint PIN_PAR2CS_CS1 = 0u;

// CS2, high active (shared with PIN_SPI_CS)
static constexpr uint PIN_PAR2CS_CS2 = 1u;

// /EW write strobe (shared with PIN_PAR_WR; must match PAR2CS_E_PIN defined
// in parallel_2cs.pio)
static constexpr uint PIN_PAR2CS_E = 2u;

// =============================================================================
// I2C slave pins (I2C0, software slave mode)
//
//   SDA → GPIO 8
//   SCL → GPIO 9
// =============================================================================
static constexpr uint PIN_I2C_SDA = 8u;
static constexpr uint PIN_I2C_SCL = 9u;
static constexpr uint I2C_SLAVE_ADDR = 0x3Cu;

// =============================================================================
// DisplayLink USB host pins (PIO USB Full-Speed, D+/D- must be adjacent)
//
// Shared with the parallel bus (D[7] = GPIO10, DC = GPIO11), so DisplayLink
// output is forbidden in PARALLEL bus mode (see outputInterfaceAllowed()).
// pio0 is dedicated to the USB host; SPI/parallel input stays on pio1.
// =============================================================================
static constexpr uint8_t PIN_USB_DP = 10u;
static constexpr uint8_t PIN_USB_DM = 11u;
static constexpr uint8_t USB_PIO_INDEX = 0u;

// =============================================================================
// Boot-time configuration GPIOs (active-low, internal pull-up)
// Default (not connected, pull-up HIGH) = primary mode.
// Driven LOW = alternate mode.
// =============================================================================
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

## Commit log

2026-05-09 Add Pico 2 example: SPI slave → DVI-D output via PicoDVI
    - example/pico2/src/main.cpp: dual-core implementation
    - Core 0: SPI ring buffer processing + DVI RGB565 scanline feeding
    - Core 1: PicoDVI TMDS encode + serialise (dvi_scanbuf_main_16bpp)
    - SPI processing runs in the q_colour_free wait loop to avoid
    starving Core 1 of colour buffers (prevents PicoDVI late-scanline
    solid-red error state)
    - example/pico2/src/spi_slave.pio: PIO1 SPI slave (Mode 0, MSB first)
    with per-byte DCX capture; supports CS-always-low wiring
    - example/pico2/include/config.h: pin assignments and compile-time constants
    - example/pico2/CMakeLists.txt: add libdvi, PIO header generation,
    DVI_DEFAULT_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
    [config.h, main.cpp]
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2026-05-09 Fix PicoDVI effective colour-buffer dimensions; add boot test pattern + frame probe
    - dvi_w: use h_active_pixels/2 — tmds_encode_data_channel_16bpp pixel-doubles each
    input pixel, so the colour buffer is half the physical DVI width (320 for 640×480).
    - dvi_h: use v_active_lines/DVI_VERTICAL_REPEAT — Core 1 reuses each TMDS buffer for
    REPEAT consecutive physical lines, so only 240 unique buffers are consumed per frame.
    - Set sl2d_cfg.dviTiming.{h,v}.active from dvi_w/dvi_h (not physical pixel counts).
    - At boot, fill the framebuffer with an 8-bar RGB565 test pattern and call
    setDisplayOn(true) so the DVI pipeline can be verified before the SPI master sends
    SLPOUT/DISPON.
    - Initia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
    [config.h, main.cpp]
2026-05-10 Fix SPI ring buffer overrun: drain more often + eliminate per-pixel division
    Ring buffer overrun root cause: Core 0 called process_spi_ring_buf() only while
    spinning on q_colour_free. When a free buffer was immediately available the
    spin ran 0 iterations, leaving SPI data to accumulate unchecked. At 62.5 MHz
    SPI the 4 KiB ring buffer overran within a few hundred microseconds of a full-
    frame RAMWR burst, corrupting the byte stream and causing accidental INVON /
    MADCTL commands to fire.
    Fix A (main.cpp): call process_spi_ring_buf() at three points per loop
    iteration — (a) inside the q_colour_free spin as before, (b) before getScanline,
    and (c) after queue_add_blocking_u32. N_SCANLINE_BU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
    [main.cpp]
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2026-05-10 Optimize Core0 throughput for 60Hz SPI input
    - Replace getScanline()+memcpy with fillScanline(line, dst): writes
    directly into the DVI buffer, eliminating ~36 MB/s of SRAM traffic
    and the intermediate scanlineBuf allocation
    - Eliminate per-pixel physIndex() multiply in writePixelRgb565: cache
    MADCTL-derived write pointer step values (cachedHStep/cachedVLineStep)
    at MADCTL/RAMWR command time; hot path becomes pointer increment only
    - Replace per-scanline vertical scaling division with fixed-point multiply
    (vStep precomputed in calcScaleParams)
    - Force-inline writePixelRgb565, writePixel, processRamwrByte, feedData
    [main.cpp]
2026-05-10 Restructure inputData hot loop: hoist switch(currentCmd/pixelFormat)
    Replace per-byte feedData(byte) call chain with bulk processRamwrData():
    - switch(currentCmd) and switch(pixelFormat) now evaluated once per
    inputData() call instead of once per byte
    - RGB565 tight loop reads byte pairs directly from the input buffer,
    bypassing the ramwrBuf accumulation for aligned data
    - feedDataByte() handles the rare MADCTL/COLMOD per-byte path
    Also incorporate user-side main.cpp optimisations: remove preparatory
    process_spi_ring_buf() calls to reduce DVI queue response latency,
    inline flush_data_batch, and consolidate the g_sl2d null-check.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
    [config.h, main.cpp]
2026-05-10 Add INVON/INVOFF polarity inversion config and CASET/RASET support
    - Sl2dConfig.invertInvPolarity: reverses INVON/INVOFF polarity for displays
    where INVON means normal (GPIO28 Low=default, High=inverted)
    - CASET (0x2A) / RASET (0x2B): set the write window for RAMWR, enabling
    partial framebuffer updates; RAMWR now starts at (casetXS, rasetYS)
    - GPIO28 repurposed from debug frame pulse output to CFG_INV_POL input
    - writePixelRgb565 row-wrap uses physIndex() instead of cachedVLineStep
    to correctly handle arbitrary CASET/RASET windows
    [config.h, main.cpp]
2026-05-11 Remove unused symbols, add English docs, configure clang-format hook
    - Apply Google coding style (clang-format) across all source files
    - Remove DviTiming struct and timing:: presets; replace
    Sl2dConfig.dviTiming with dviWidth/dviHeight (only active area dimensions
    are used by the library)
    - Drop VERSION_MAJOR/MINOR/PATCH constants (no references in the project)
    - Drop Impl::cachedLogW/H/VLineStep (assigned but never read)
    - Rewrite top-level README.md in English with API reference for
    Sl2dConfig, HostInterface, and SpiLcd2Dvi
    - Add example/pico2/README.md: pin assignment table, configuration GPIO
    descriptions, and PicoDVI/libdvi usage notes
    - Add .claude/settings.json: PostToolUse h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
    [config.h, main.cpp]
2026-05-11 Add multi-controller abstraction: ControllerBase + St7789Controller
    - Introduce Controller enum and getDefaultConfig() to the public API
    - Refactor internal PIMPL from flat Impl struct to ControllerBase
    abstract class with St7789Controller as the first concrete subclass
    - ST7789-specific logic (madctl, command dispatch) isolated in
    St7789Controller; common state and hot-path pixel processing
    (processRamwrData, writePixelRgb565, feedData) remain in ControllerBase
    - Controller instance allocated with new/delete; only the framebuffer
    uses host.alloc/free to allow placement in external memory (PSRAM etc.)
    - Remove calcRequiredMemory (no longer meaningful with virtual dispatch)
    - Move ST7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
    [config.h, main.cpp]
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2026-05-14 pico2_ssd1306: replace parallel slave with direct SPI slave via PIO
    Remove the 74HC595/74HC4040/74AHC1G04 external circuit and receive SPI
    signals directly on GPIO. New spi_slave.pio samples MOSI and DCX
    simultaneously on each SCLK rising edge with the loop unrolled for
    3 instructions/bit, giving f_max = 84 MHz at 252 MHz system clock.
    Pin changes: RESX 22→1, I2C SDA 0→8, I2C SCL 1→9;
    SPI SCLK=2, MOSI=4, DCX=5, CS=6 (direct connections).
    Add CS rising-edge GPIO IRQ to reset the PIO SM between transactions.
    [config.h, main.cpp]
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2026-05-15 examples: make framebuffer size configurable at build time
    Add LCDTAP_LCD_SIZE_{W,H,ALT_W,ALT_H} compile options to all three sample
    programs. Defaults are defined in config.h via #ifndef/#define so the source
    is self-documenting; CMakeLists.txt forwards values only when explicitly
    passed via cmake -D. Update README files with option tables and correct the
    LCD_SIZE GPIO table (Low=240x320, High=320x240 for st7789/3line_spi).
    [config.h, main.cpp]
2026-05-15 add LcdTapConfig.swapRB and PIN_CFG_SWAP_RB (GPIO 22)
    - Add bool swapRB to LcdTapConfig; in updateWriteCache() the MADCTL BGR
    bit is XOR'd with swapRB so the R/B swap can be overridden at boot time
    independently of the LCD command stream.
    - Move PIN_CFG_CLK_MODE from GPIO 22 to GPIO 0 in pico2_st7789.
    - Add PIN_CFG_SWAP_RB = GPIO 22 to both pico2_st7789 and pico2_3line_spi;
    LOW (default) = no swap, HIGH = swap R and B channels.
    - Update README files and schematics accordingly.
    [config.h, main.cpp]
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2026-05-16 Add multi-interface support to pico2_universal with OSD selection
    - Integrate I2C slave (from pico2_ssd1306) and 3-line SPI (from pico2_3line_spi)
    - Rename PIO files: spi_slave→spi_4line_mode0, par_slave→parallel_8bit,
    3line_spi_slave→spi_3line_mode0
    - Add OSD onMenuOpen callback to lib for host-injected menu items
    - Insert Interface item (I2C / 4Line SPI / 3Line SPI / Parallel) at OSD index 1
    - Dynamic interface switching via switchInterface() on Apply (no reboot needed)
    - Extend ConfigFile to include interfaceType alongside LcdTapConfig
    - Remove GPIO0 (Normal/Fast mode strap); interface now persisted in flash
    - I2C ring buffer uses direct inputData() stride like SPI (no dataBatch)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
    [config.h, main.cpp]
2026-05-17 pico2_ssd1306: pass ring buffer directly to inputData, fixing red line artifact
    Replace the intermediate dataBatch copy with direct ring buffer pointer
    passing (stride=sizeof(uint32_t)), matching pico2_universal/pico2_st7789.
    The old batching approach caused stale data to bleed across frames at high
    frame rates, producing a red horizontal line artifact.
    [config.h, main.cpp]
2026-05-17 Fix RESX handler to re-sample GPIO level, preventing stuck reset on simultaneous edges
    When EDGE_FALL and EDGE_RISE were detected in the same IRQ callback,
    the old logic passed `(events & EDGE_FALL) != 0` which could leave
    inputReset asserted if both edges fired together. The fix explicitly
    calls inputReset(true) + resetPioSm() on FALL, then re-samples the
    actual pin level with gpio_get() so the final reset state always
    reflects reality. Also adds resetPioSm() helper to all three examples
    and stores gSpiProgOffset for fast (parallel) mode in pico2_st7789.
    [main.cpp]
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2026-05-18 Remove CS-rise PIO SM reset to fix command drop race condition
    Resetting the SM from a CPU IRQ on CS de-assertion introduced a race:
    if CS was re-asserted before the handler completed, the leading bits of
    the next transaction were lost. Remove the feature from all three
    examples (pico2_universal, pico2_st7789, pico2_ssd1306). RST-pin SM
    reset is retained.
    [main.cpp]
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2026-05-20 move DVI scanline filling to repeating timer on pico2_universal
    Replaces the inline fillScanline/queue loop in the Core0 main loop with
    a repeating timer callback (200 µs interval). The callback preempts the
    main loop as a Core0 IRQ, so long-running SSD1331 drawing commands can
    no longer starve the DVI output queue.
    [main.cpp]
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2026-05-20 apply repeating timer DVI scanline fill to pico2_st7789
    Port the same dviTimerCallback pattern from pico2_universal: move DVI
    scanline filling into a repeating timer IRQ (200 µs) so the main loop
    is not rate-limited by q_colour_free availability. This prevents DVI
    output glitches when the main loop is delayed by SPI processing.
    [main.cpp]
2026-05-20 apply repeating timer to pico2_ssd1306; fix I2C IRQ priority
    pico2_ssd1306: port dviTimerCallback from pico2_universal to prevent DVI
    glitches under SPI/I2C processing load.
    Both examples: elevate I2C0_IRQ to PICO_DEFAULT_IRQ_PRIORITY>>1 (0x40)
    so it can preempt the repeating timer callback (0x80). Without this,
    equal-priority IRQs cannot preempt each other on Cortex-M33; the timer
    callback blocks I2C draining, fills the 16-entry FIFO, causes clock
    stretching, and may trigger a master timeout that aborts the transaction,
    desynchronizing the SSD1306 address state (row shifts, screen flips,
    blackout).
    [main.cpp]
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2026-05-24 Add USB CDC serial interface and Web Serial monitor
    - Add uart_if module (uart_if.hpp / uart_if.cpp) implementing a
    JSON-over-CRLF command protocol on USB CDC stdio:
    hello, getparams, setparams, getframebuffer,
    cmddump_start/abort/forcetrigger/getstatus/read
    - Add writeProtected API to LcdTap to suppress RAMWR during readout
    - Fix Lexer deferredChar bug: boolean literal followed immediately by '}'
    caused BRACE_CLOSE to overwrite BOOL_FALSE in pending token, making
    every setparams call fail with a parse error
    - Fix FB_DATA and DUMP_DATA base64 streaming: advance position counter
    before b64Feed and always feed both low/high bytes so that a CDC-full
    drain failure never drops the h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
    [main.cpp]
2026-05-25 pico2_universal: move fillScanline to Core 1 to free Core 0 for SPI processing
    Replace the repeating-timer IRQ approach (dviTimerCallback on Core 0 every
    200 µs) with a unified Core 1 loop that performs fillScanline + TMDS encode
    back-to-back. Core 0 is now free to drain the SPI/I2C ring buffer without
    timer preemption, improving throughput at high SPI clock rates.
    Key changes:
    - core1Main: custom loop replaces dvi_scanbuf_main_16bpp; pulls from
    q_colour_free, calls fillScanline + gOsd.fillScanline, TMDS-encodes
    via tmds_encode_data_channel_16bpp, submits to q_tmds_valid.
    q_colour_valid is bypassed.
    - dviTimerCallback and repeating_timer removed from Core 0.
    - gDviH assignment moved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
    [main.cpp]
2026-05-25 pico2_st7789, pico2_ssd1306: move fillScanline to Core 1 (port from pico2_universal)
    Port the Core 1 unified loop from pico2_universal (0f3f2df):
    q_colour_free, calls fillScanline, TMDS-encodes via
    tmds_encode_data_channel_16bpp, submits to q_tmds_valid.
    - gDviH assignment moved before multicore_launch_core1 (ordering fix).
    - gScanY/gFrame/gLed/gDviTimer globals removed; state is now Core 1-local.
    - scanlineBufs aligned(4) for safe uint32_t* cast to TMDS encode functions.
    - hardware/timer.h include removed; tmds_encode.h added with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
    [main.cpp]
2026-05-25 pico2_common: extract SPI/I2C/DVI drivers into shared library
    Extract common peripheral driver code from the three example
    main.cpp files into example/pico2_common/ as a static library:
    - lcdtap::pico2::SpiSlaveState / spiSlaveInit / spiSlaveProcess /
    spiSlaveDeinit / spiSlaveResetSm / spiSlaveInitDma
    - lcdtap::pico2::I2cSlaveState / i2cSlaveInit / i2cSlaveProcess /
    i2cSlaveDeinit
    - lcdtap::pico2::DviOutState / dviOutPrepare / dviOutLaunchCore1 /
    dviOutConsumeNewFrame (Core 1 fillScanline+TMDS loop)
    - spi_4line_mode0.pio moved from each example into pico2_common/src/;
    erroneous 'wait 1' comment in the universal version fixed to 'wait 0'
    Each example's CMakeLists.txt and main.cpp up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
    [i2c_slave.cpp, main.cpp, spi_slave.cpp]
2026-05-25 pico2_universal: fix crash after flash write by replacing multicore_lockout with cooperative pause
    multicore_lockout_victim_init() spins Core 1 in IRQ context (SIO_IRQ_PROC1).
    At equal priority, DMA_IRQ_0 cannot preempt it, so during the ~100 ms flash
    erase the DMA consumes all TMDS buffers without returning them to q_tmds_free.
    After lockout ends Core 1 blocks forever in queue_remove_blocking_u32() and DVI
    output stops.
    Replace with a cooperative pause flag (flashPauseReq / flashPauseAck):
    - Core 1 checks the flag at the top of its scanline loop, before any
    flash-resident call (fillScanline, OSD fillScanline). It returns the colour
    buffer to the queue, sets flashPauseAck, and enters W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
    [main.cpp]
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2026-06-22 replace PicoDVI with RP2350 HSTX native output
    Replace the PicoDVI software-TMDS library with a custom driver using the
    RP2350's built-in HSTX peripheral. DMA channels are chained in a 3-slot
    round-robin so Core 1 fills line buffers while HSTX transmits, removing the
    per-scanline IRQ budget constraint that caused video loss under heavy load.
    Also fix RP2350-E5 errata: clear EN bit on all chained DMA channels before
    dma_channel_abort() in hstxOutFlashAcquire() to prevent auto-chain
    re-triggering that caused ~50% video loss after flash writes.
    Remove PicoDVI submodule; update README files and LICENSE accordingly.
    [config.h, hstx_out.cpp, main.cpp]
2026-06-23 fix QMI flash clock overspeed on Raspberry Pi Pico2
    setQmiTiming() used CLKDIV=2, giving QSPI SCK = clk_sys/2 = 156 MHz at
    312 MHz system clock. This exceeds the W25Q16JV flash spec (133 MHz max)
    used on Pico2, causing intermittent flash read errors and system crashes.
    Increase CLKDIV to 3 (0x40000202 → 0x40000203): QSPI SCK = 312/3 = 104 MHz,
    well within spec. RXDELAY=2 remains appropriate at this clock speed.
    The Pimoroni reference runs at 264 MHz with CLKDIV=2 (132 MHz QSPI, just
    within spec). Custom boards with faster flash chips are unaffected at 156 MHz.
    [hstx_out.cpp]
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2026-07-10 Remove I2C self-master test scaffolding
    The I2C slave reception was fixed by tuning i2c_ll_set_sda_timing and
    i2c_ll_master_set_filter, so the bit-banged self-test master added for
    diagnosis is no longer needed. Drops i2c_selftest.{hpp,cpp}, its config
    flags/pins, and the periodic invocation. The I2C bus sniffer and slave
    diagnostic counters are kept.
    [app_config.h, main.cpp]
2026-07-10 OSD/keypad IMU orientation tracking, plus bring-up fixes
    - OSD is now rendered to an offscreen raster and composited rotated by
    the IMU orientation, so it always reads upright to the user (was
    fixed-panel-orientation before). Osd::getState() added to the core
    library so the compositor can skip rendering while hidden.
    - Fixed a BMI270 init race in M5.begin() (occasionally left M5.Imu
    disabled for the whole session) by retrying Imu.begin() a few times
    in setup().
    - Corrected imu_orient.cpp's accel-to-quadrant mapping, which had never
    been validated against real tilt data before the BMI270 fix (it was
    consistently one quadrant off).
    - Fixed the keypad's icon rotation formula: the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
    [main.cpp]
2026-07-10 m5tab5: accelerate panel output with ESP32-P4 PPA, fixing 10fps stall
    M5.Display.setRotation(3) forced pushImage()/writeImage() onto M5GFX's
    slow generic per-pixel rotate path (only the r==0 fast memcpy path is
    contiguous), turning every 1280x40 strip write into ~1280 scattered
    small copies into the physical 720x1280 DSI framebuffer. Bypass that
    path entirely: rotate each strip with the ESP32-P4 PPA (SRM) and write
    it straight into the panel framebuffer obtained via M5GFX's public
    Panel_DSI/Panel_Device accessors, with double-buffered strips so CPU
    fill and PPA transfer overlap. Falls back to the old pushImage() path
    if PPA/panel introspection fails.
    Bring-up on real hardware caught two bug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
    [app_config.h]
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2026-07-10 m5tab5: consolidate PPA transfers to one per frame, add PPA busy-time metric
    Profiling (wait+fill+strip+submit stayed ~2.9-3.0ms/strip regardless of
    how much extra CPU work OSD/keypad compositing added) showed the ESP32-P4
    PPA transaction itself, not CPU compute, is the rate-limiting resource.
    The output block's height is always the full 1280 physical rows
    regardless of STRIP_LINES -- only its width changes -- so the previous
    STRIP_LINES=40 (18 transfers/frame) made PPA issue 18x1280 short (80-byte),
    strided row bursts into the panel framebuffer per frame instead of far
    fewer, longer, contiguous ones. Set STRIP_LINES to the full panel height
    (720) so displayOutRenderFrame's existing loop nat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
    [app_config.h, main.cpp]
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2026-07-10 m5tab5: switch to native portrait orientation, drop PPA workaround
    STRIP_LINES tuning (720, then 120) gave diminishing or negative returns
    (13.3fps, 15.8fps vs the earlier 16-17fps), and a new intermittent
    flicker appeared. Rather than continue fighting the PPA-rotate
    workaround, address the root cause: the Tab5 panel is physically
    portrait (720x1280), but the app ran it at setRotation(3) (logical
    1280x720 landscape), forcing every pushImage() through M5GFX's slow
    generic per-pixel rotate path -- which is what the whole PPA direct-blit
    apparatus (ppa_blit.cpp) existed to work around.
    Switch to setRotation(0) (native physical orientation) so logical and
    physical orientation match, letting M5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
    [app_config.h, main.cpp]
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2026-07-10 m5tab5: prefer internal SRAM for LcdTap framebuffer and strip buffers
    Both were PSRAM-only. The LcdTap controller framebuffer (main.cpp's
    former psramAlloc, now smartAlloc) is written per-pixel by incoming
    command data and read by fillScanline()'s scanline gather -- a strided
    column read for odd output rotations -- so moving it to internal SRAM
    (falling back to PSRAM if a large controller/preset size doesn't fit)
    should cut both access costs directly. The strip buffers
    (display_out.cpp) are the async-copy source read by the DMA engine every
    strip; keeping them off PSRAM means the DMA read no longer shares bus
    bandwidth with the DMA write side (the panel framebuffer, which must
    stay in PSRAM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
    [main.cpp]
2026-07-10 m5tab5: revert OSD buffer to PSRAM-only; static framebuffer pool doesn't fit
    Real hardware showed that putting both the LcdTap framebuffer and the
    OSD raster in internal SRAM starved the async_memcpy DMA engine's own
    link-list allocation ("no mem for link list items"), corrupting the
    display. Moving the OSD raster back to PSRAM-only (it's touched only
    while the OSD menu is open, not every frame) fixed it and pushed
    throughput above 30fps -- confirming the framebuffer's internal-SRAM
    placement (kept as-is, smartAlloc with PSRAM fallback) is the change
    that matters.
    Also attempted replacing smartAlloc with a static internal-SRAM pool
    (mirroring example/pico2_universal/src/main.cpp's memPool/p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
    [app_config.h, main.cpp]
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2026-07-11 m5tab5: port application to ESP-IDF (main.cpp, capture, NVS)
    Replaces the remaining Arduino-framework glue with ESP-IDF
    equivalents; M5Unified/M5GFX API usage (M5.begin/Display/Touch/Imu)
    is unchanged.
    - Serial.* -> ESP_LOGx (main.cpp, parlio_spi_slave.cpp); the hex raw-
    dump loop is built into one buffer first so it stays a single log
    line instead of one ESP_LOGx call per byte.
    - delay()/setTxTimeoutMs(0) -> vTaskDelay() + usb_serial_jtag_vfs_
    use_nonblocking(), so logging never blocks with no host attached.
    - ESP.getPsramSize() -> heap_caps_get_total_size(MALLOC_CAP_SPIRAM).
    - Preferences -> nvs_open/nvs_get_blob/nvs_set_blob, same namespace/
    key ("lcdtap"/"cfg") so a device alrea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
    [main.cpp, parlio_spi_slave.cpp, ram_pool.cpp]
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2026-07-11 m5tab5: pull up SPI capture CS to fix post-boot-idle capture lockup
    If the SPI host connects more than ~5s after boot, the display never
    comes up: display_task's capture watchdog re-realigns the PARLIO
    capture whenever isrChunks hasn't advanced for 5s, which fires
    whenever the master hasn't started sending yet. With CS floating at
    that moment, priming can settle it low; spi_deser.hpp's
    discardUntilIdle barrier only clears on a genuine CS-idle sample, so
    if CS never reads idle again the interface stays stuck decoding
    nothing for the rest of the session, even once the master starts for
    real. Confirmed on hardware: csFrames=1/rx=0 forever, raw dump reads
    constant 0x22 (CS asserted, D/C=1, MOSI=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
    [parlio_spi_slave.cpp]
2026-07-11 m5tab5: bound the post-realign discard barrier (fixes SPI lockup)
    The CS pull-up added in e37d9e5 didn't fix the "start the SPI host
    >5s after boot" lockup -- new hardware logs (csFrames=1/rx=0 forever,
    raw dump constant regardless of the pull-up) plus "restarting the
    host sometimes recovers with glitches, never within 5s" point to a
    different root cause: discardUntilIdle only ever clears on a genuine
    CS-idle sample, but a single-drop SPI master (Arduboy) has no reason
    to release CS between transactions -- it can assert CS once at boot
    and hold it for the whole session. If the capture watchdog's 5s
    periodic realign (or a RESX-triggered barrier) lands before such a
    master starts, the barrier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
    [main.cpp, parlio_spi_slave.cpp, spi_deser_test.cpp]
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
